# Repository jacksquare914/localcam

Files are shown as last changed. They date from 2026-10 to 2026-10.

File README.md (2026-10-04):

# LocalCam-1 — a local-only WiFi camera

A small 4-layer board that turns a **Luckfox Core1106** system-on-module (Rockchip
RV1106G3) into a network camera that never talks to anyone's cloud. A MIPI CSI-2 sensor
comes in over an FPC, the module encodes H.264/H.265 on-chip, and the stream is served
over RTSP to a local [Frigate](https://frigate.video/) NVR. Object detection runs on the
module's own 1 TOPS NPU, on the camera, not on a server and not on someone else's GPU.

**75 × 44 mm, 4 layers, 1.6 mm, built by JLCPCB.** USB-C in, microSD for storage, a
debug UART header and a recovery button.

> **Status: not ready to order.** 226 of 228 netted pads are connected. Two signals still
> need a trace and both need a part nudged rather than more routing effort — see
> [What is still open](#what-is-still-open). Everything else has been verified; the
> evidence is in [`logs/`](logs/).

---

## Why this board exists

Every consumer camera in this class wants an account, an app, and an outbound
connection. The goal here is the opposite: a camera that is useful precisely because it
is isolated. Four requirements drove the whole design.

1. **Nothing leaves the LAN.** No cloud service, no phone-home, no vendor account. RTSP
   to a local NVR and that is all.
2. **Detection happens on the camera.** The RV1106G3's NPU runs the model, so there is
   no video streaming off-box just so a server can look at it.
3. **It must be repairable and legible.** A board you cannot read is a board you cannot
   fix. That drove the routing style (below) as much as any electrical requirement.
4. **One cable.** USB-C supplies it; everything else is optional.

## What is on it

| | |
|---|---|
| **U1** | Luckfox Core1106 — RV1106G3, Cortex-A7 + RISC-V MCU + NPU + ISP, 256 MB DDR3L, onboard WiFi and 8 GB eMMC options |
| **J3** | 24-pin 0.5 mm FPC to the camera sensor — 2 MIPI data lanes + clock, I²C, MCLK, reset, power-down |
| **J1** | USB-C 2.0 receptacle — power in and USB device, with CC pull-downs and an ESD part (U2) |
| **J2** | microSD (Hirose DM3AT), 4-bit SDMMC, with card-detect |
| **H1** | 5-pin debug header — UART2 plus the recovery line |
| **S1** | reset, **D2** status LED, **F1** 1.5 A polyfuse, **D1** TVS on the 5 V rail |

Full pad-by-pad detail, cross-checked against the vendor pinout, is in
[`docs/pin-assignment-crosscheck.md`](docs/pin-assignment-crosscheck.md).

---

## The design decisions worth arguing about

[`docs/INTENT.md`](docs/INTENT.md) is the long version. The short version:

**The stack-up decides everything.** JLCPCB **JLC04161H-7628**: the 0.2104 mm of 7628
prepreg between F.Cu and the ground plane is the only reason the camera pairs can be
100 Ω. *If you let the fab substitute a stack-up, the pairs silently stop being 100 Ω.*
The order settings are printed by `hardware/make-fab.sh` for exactly that reason.

**In1.Cu is a plane, not a routing layer.** A MIPI pair's return current flows in the
copper directly beneath it; a slot cut in that plane is the classic reason a camera link
passes on the bench and drops frames when the enclosure warms up. The router physically
cannot place a non-GND track there.

**The camera pairs are routed as one trace, then split.** A single centreline is routed
at the full pair width and both traces are generated as parallel offsets of it, so the
gap is constant by construction and the lengths are identical:

| pair | leg / leg | intra-pair skew |
|---|---|---|
| CSI_D1 | 14.51 / 14.51 mm | **0 µm** |
| CSI_CLK | 14.72 / 14.72 mm | **0 µm** |
| CSI_D0 | 14.92 / 14.92 mm | **0 µm** |

Budget was 100 µm. Inter-pair spread is 410 µm against a 1000 µm budget. No pair changes
layer and no pair has a via.

**Orthogonal everywhere, with one deliberate exception.** Every trace runs parallel or
perpendicular to a board edge — 480-odd segments of it — except **18 chamfers, all six
of which belong to camera-pair traces**. Routed fully orthogonal the clock pair could not
stay coupled in the shared FPC channel and came out at 3.0 mm skew, which is a dead MIPI
link. Eighteen chamfers in one corridor buy back 0 µm on all three pairs. Everywhere
else there is room, so nothing cuts a corner.

**The USB-C data pads cross with no vias at all.** A 12-pin receptacle interleaves its
two D− pads with its two D+ pads at 0.5 mm pitch, so the two shorting links must cross
exactly once. A via pair does not fit — a 0.6 mm via needs 0.5 mm of clear radius and the
neighbouring pad edge is 0.35 mm away. So one net crosses *above* the pad row, inside the
connector body, and the other crosses *below* it. They never meet.

**Power rails live on In2.Cu, one via per group.** 0.5 mm of 1 oz outer copper carries
1.44 A at a 10 °C rise (IPC-2221) and the module draws about 0.6 A. +5V and VBUS_IN vias
are doubled, because a single plated barrel carrying a whole rail is the classic
warm-attic failure.

---

## Defects found and fixed along the way

These were real, and most were caught by review rather than by the person who made them.

| # | Defect | Why it mattered |
|---|---|---|
| A-7 | Pad 76 (`VCC3V3_RTC`) had been tied to +3V3 | It sits behind a Schottky inside the module; tying it shorts across that diode. Now deliberately unconnected. |
| A-8 | Camera I²C pull-ups went to +3V3 | Pads 16/17 are in the module's **1.8 V** IO domain — the vendor pinout confirms it. Pulling them to 3.3 V over-drives 1.8 V pins. Now on `+1V8`. |
| A-9 | `VBUS_DET` divider was fed from +3V3 | 100k/100k from 3.3 V gives 1.65 V into pad 24 (`USB_VBUSDET`, a **3.3 V** input) — *below* V_IH, so the pin sat in the indeterminate band. Now from +5V: 2.5 V, a valid high. |
| A-10/11 | No decoupling on +1V8; +5V bulk 71 mm from the module | ~60 mV of droop at 0.6 A with nothing local to absorb a WiFi transmit burst. Added C7 (100 nF on +1V8) and C8 (10 µF local +5V bulk). |
| A-12 | Ground pour ran flush to the board edge | Ignored the 2 mm corner fillets. Now inset 0.25 mm, following the radius. |
| A-13 | Three vias sat **inside pads** | Via-in-pad wicks solder paste during reflow and is not offered at this price tier. |
| A-14 | Two pairs of drills physically overlapped | −0.008 and −0.120 mm hole-to-hole against a 0.20 mm minimum. The fab would have rejected it. |
| A-15 | U2 (the USB ESD part) **was not grounded** | Its ground pad is fenced in by the USB traces, so the pour could not reach it. It now has its own via to the plane. |
| A-16 | The microSD **card-detect pins were not in the netlist at all** | J2 pins 9/10 had no net, so no connectivity check could report them. The stock `Micro_SD_Card` symbol has no such pins; J2 now uses `Micro_SD_Card_Det2`, which matches the DM3AT footprint pin for pin. |

A-15 and A-16 are the instructive ones: both were invisible to a net-level check. A net
with two pads and one trace looks complete whether or not a *third* pad is stranded, and
a pad with no net cannot be reported as disconnected at all. That is what
`tools/padaudit.py` exists to catch.

---

## Repo layout

```
hardware/     the KiCad 10 project — open LocalCam1.kicad_pro
  lib/        the Core1106 symbol and footprint (not in KiCad's stock libraries)
  make-fab.sh one-shot JLCPCB output generator; run it on a machine with KiCad 10
tools/        the sources of truth and the checkers
  spec.py       NETLIST source of truth — 36 parts, 36 nets. Edit this, never the schematic
  placement.py  PLACEMENT source of truth — part positions and the zone list
  gen.py        spec.py  -> LocalCam1.kicad_sch
  genpcb.py     spec.py + placement.py -> LocalCam1.kicad_pcb (placed, netted, unrouted)
  hroute5.py    the router (orthogonal, with coupled differential pairs)
  hroute6.py    the finisher — routes only what is missing, keeping existing copper
  continuity.py per-net island count + true minimum copper-to-copper gap
  padaudit.py   PER-PAD audit with the ground pour simulated  <- the one that finds real bugs
docs/         design intent, the pinout, the cross-check, routing and mechanical notes
vendor/       Luckfox's own Core1106 pinout spreadsheet, module PDF and footprint package
logs/         verification output, kept as evidence rather than summarised
```

## Building and checking it

The schematic and the board are **build outputs**. Do not hand-edit them and expect the
edit to survive.

```bash
cd tools
export KICAD_SYMBOL_DIR=/usr/share/kicad/symbols     # wherever yours live
python3 gen.py        # -> LocalCam1.kicad_sch
python3 genpcb.py     # -> LocalCam1.kicad_pcb  (placed, netted, unrouted)
python3 hroute5.py base.kicad_pcb routed.kicad_pcb   # route it
```

Then check it with something that did not do the routing:

```bash
python3 padaudit.py   ../hardware/LocalCam1.kicad_pcb   # per-pad, pour simulated
python3 continuity.py ../hardware/LocalCam1.kicad_pcb --clearance
```

`padaudit.py` walks every pad that carries a net and answers one question: is this pad in
the same electrical island as the rest of its net? It simulates the ground pour, because
the board ships with pours unfilled so KiCad recomputes them — without that simulation
every GND pad looks disconnected and the answer is useless.

**Fill the zones in KiCad (press `B`) and save before plotting**, or the pours are not in
the Gerbers and the ground plane simply does not exist.

Requires `numpy` and `scipy`.

## Verified, on the delivered board

```
226 / 228 netted pads connected        (pour simulated)
499 segments: 481 orthogonal, 18 chamfers on camera pairs, 0 other angles
108 vias, all 0.6 / 0.3 mm             (0.15 mm annular ring, min is 0.13)
minimum copper-to-copper gap 0.150 mm  (JLCPCB floor is 0.09)
camera pairs: 0 µm intra-pair skew, 410 µm inter-pair spread
45 of 45 used module pads agree with the vendor pinout
```

## What is still open

Two signals, both placement problems rather than routing ones:

| Net | Pad | At | What to do |
|---|---|---|---|
| `SD_D3` | J2.2 | (55.78, 28.51) | Six SD signals funnel through one gap between the module and the socket and D3 does not fit. Give it B.Cu with a via each side, or shift J2 about a millimetre. |
| `VBUS_DET` | R7.2 | (19.41, 32.60) | R7 sits in the channel the USB pair needs between U2 and the module edge. Move it clear — toward y ≈ 35.5 — or rotate it 90°. |

The router was given every chance at these: shape search, two-layer maze, two rip-up
rounds at widening corridors, and a last-resort pass at 0.15 mm / 0.10 mm. Each attempt
either gained nothing or broke three other nets to fix one, and reported that rather than
claiming a win.

**Open question for review:** `R7` currently divides **+5V** (post-fuse). Dividing
**VBUS_IN** (pre-fuse) is what the pin name literally means and still reads high if the
polyfuse opens; +5V instead answers "is my rail actually up?". Both give 2.5 V and both
are valid. One line in `spec.py`.

## Reviewing this board — where to look first

If you have ten minutes: [`docs/INTENT.md`](docs/INTENT.md) §4 for the arguable decisions,
then `logs/VERIFY-pads.log` for what is actually connected. If you have an hour, run
`padaudit.py` yourself and disagree with it.

Things I would most like a second opinion on:

- The two open nets above — is nudging R7 and J2 the right call, or should the floorplan
  change more deeply?
- The USB pair is **not** coupled between U1 and U2, because U2's +5V pin sits physically
  between D− and D+. Over ~8 mm at USB 2.0 that should be fine. Second opinion welcome.
- `+5V` reaches the module through a ~71 mm path. C8 was added locally to cover it, but a
  different floorplan would shorten the path instead.
- Whether grounding both card-detect pins is the right choice versus bringing one out to
  a GPIO with a pull-up.

## Sources

- Luckfox Core1106 pinout, schematic and footprint package —
  <https://wiki.luckfox.com/Core1106/Pinout/> (the files are mirrored in `vendor/`)
- Rockchip RV1106 datasheet V1.7 —
  <https://files.luckfox.com/wiki/Luckfox-Pico/PDF/Rockchip%20RV1106%20Datasheet%20V1.7-20231218.pdf>
- Core1106 product page — <https://www.luckfox.com/Core1106>
- Trace current capacity: IPC-2221. Differential microstrip geometry: IPC-2141.
- JLCPCB capabilities and the JLC04161H-7628 stack-up: JLCPCB's own capability pages.

## Licence

No licence has been chosen yet — which by default means all rights reserved, so pick one
before sharing this widely.

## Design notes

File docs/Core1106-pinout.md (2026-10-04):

# Core1106 pinout — vendor table, with this board's net on every pad

Source: `Core1106-PinOut.xls` from Luckfox's Core1106 footprint package
(<https://wiki.luckfox.com/Core1106/Pinout/>). The vendor columns are reproduced
verbatim; the **Net** column is what LocalCam-1 connects, and blank means the pad is
deliberately left unconnected.

112 castellated pads, 1.0 mm pitch, pad 1 at the arrow, numbered counter-clockwise.

| Pad | Vendor pin name | IO domain | Net on this board | Vendor remark |
|----:|---|:--:|---|---|
| 1 | `VI_CIF_D2_M0/MIPI_CSI_RX_CK1N/LVDS_RX_CK1N/GPI3_B2_d` | 1.8V | — |  |
| 2 | `VI_CIF_D3_M0/MIPI_CSI_RX_CK1P/LVDS_RX_CK1P/GPI3_B3_d` | 1.8V | — |  |
| 3 | `VI_CIF_D0_M0/MIPI_CSI_RX_D3N/LVDS_RX_D3N/GPI3_B0_d` | 1.8V | — |  |
| 4 | `VI_CIF_D1_M0/MIPI_CSI_RX_D3P/LVDS_RX_D3P/GPI3_B1_d` | 1.8V | — |  |
| 5 | `VI_CIF_D4_M0/MIPI_CSI_RX_D2N/LVDS_RX_D2N/GPI3_B4_d` | 1.8V | — |  |
| 6 | `VI_CIF_D5_M0/MIPI_CSI_RX_D2P/LVDS_RX_D2P/GPI3_B5_d` | 1.8V | — |  |
| 7 | `VI_CIF_D6_M0/MIPI_CSI_RX_D1N/LVDS_RX_D1N/GPI3_B6_d` | 1.8V | **CSI_D1_N** |  |
| 8 | `VI_CIF_D7_M0/MIPI_CSI_RX_D1P/LVDS_RX_D1P/GPI3_B7_d` | 1.8V | **CSI_D1_P** |  |
| 9 | `VI_CIF_D8_M0/MIPI_CSI_RX_CK0N/LVDS_RX_CK0N/GPI3_C0_d` | 1.8V | **CSI_CLK_N** |  |
| 10 | `VI_CIF_D9_M0/MIPI_CSI_RX_CK0P/LVDS_RX_CK0P/GPI3_C1_d` | 1.8V | **CSI_CLK_P** |  |
| 11 | `VI_CIF_CLKI_M0/MIPI_CSI_RX_D0N/LVDS_RX_D0N/GPI3_C2_d` | 1.8V | **CSI_D0_N** |  |
| 12 | `VI_CIF_HREF_M0/MIPI_CSI_RX_D0P/LVDS_RX_D0P/GPI3_C3_d` | 1.8V | **CSI_D0_P** |  |
| 13 | `VI_CIF_D15/PWM1_M2/GPIO3_D3_d` | 1.8V | **CAM_PWDN** |  |
| 14 | `VI_CIF_D14/UART5_CTS_M2/I2C3_SDA_M2/GPIO3_D2_d` | 1.8V | — |  |
| 15 | `VI_CIF_D13/UART5_RTS_M2/I2C3_SCL_M2/GPIO3_D1_d` | 1.8V | — |  |
| 16 | `VI_CIF_D11/UART5_TX_M2/I2C4_SCL_M2/GPIO3_C7_d` | 1.8V | **CAM_SCL** |  |
| 17 | `VI_CIF_D12/UART5_RX_M2/I2C4_SDA_M2/GPIO3_D0_d` | 1.8V | **CAM_SDA** |  |
| 18 | `VI_CIF_VSYNC_M0/GPIO3_C5_d` | 1.8V | **CAM_RST** |  |
| 19 | `VI_CIF_CLKO_M0/MIPI_CLK0_OUT/GPIO3_C4_d` | 1.8V | **MCLK0** |  |
| 20 | `VI_CIF_D10/PWM7_IR_M2/MIPI_CLK1_OUT/GPIO3_C6_d` | 1.8V | — |  |
| 21 | `GND` | - | **GND** |  |
| 22 | `USB_N` | - | **USB_DM** |  |
| 23 | `USB_P` | - | **USB_DP** |  |
| 24 | `USB_VBUSDET` | 3.3V | **VBUS_DET** |  |
| 25 | `GND` | - | **GND** |  |
| 26 | `SARADC_IN0/GPIO4_C0_z` | 1.8V | **ADC0_RECOV** |  |
| 27 | `SARADC_IN1/PWM1_M1/GPIO4_C1_z` | 1.8V | — |  |
| 28 | `GND` | - | **GND** |  |
| 29 | `GND` | - | **GND** |  |
| 30 | `CODEC_LINEOUT` | 1.8V | — |  |
| 31 | `CODEC_MICBIAS` | 1.8V | — |  |
| 32 | `CODEC_MIC0N` | 1.8V | — |  |
| 33 | `CODEC_MIC0P` | 1.8V | — |  |
| 34 | `CODEC_MIC1N` | 1.8V | — |  |
| 35 | `CODEC_MIC1P` | 1.8V | — |  |
| 36 | `GND` | - | **GND** |  |
| 37 | `EMMC_D0/FSPI_D0/GPIO4_A4_u` | 3.3V | — | When EMMC is installed, it will be disconnected. |
| 38 | `EMMC_D1/FSPI_D1/GPIO4_A3_u` | 3.3V | — |  |
| 39 | `EMMC_D2/FSPI_D2/GPIO4_A2_u` | 3.3V | — |  |
| 40 | `EMMC_D3/FSPI_D3/GPIO4_A6_u` | 3.3V | — |  |
| 41 | `EMMC_D4/SPI1_CS0_M0/UART1_TX_M2/I2C2_SDA_M1/GPIO4_A5_u` | 3.3V | — |  |
| 42 | `EMMC_D5/SPI1_CLK_M0/UART1_RX_M2/I2C2_SCL_M1/GPIO4_A7_u` | 3.3V | — |  |
| 43 | `EMMC_D6/SPI1_MOSI_M0/UART0_TX_M2/I2C0_SCL_M1/GPIO4_A1_u` | 3.3V | — |  |
| 44 | `EMMC_D7/SPI1_MISO_M0/UART0_RX_M2/I2C0_SDA_M1/GPIO4_A0_u` | 3.3V | — |  |
| 45 | `EMMC_CMD/FSPI_CS0/GPIO4_B0_u` | 3.3V | — |  |
| 46 | `EMMC_CLK/FSPI_CLK/GPIO4_B1_d` | 3.3V | — |  |
| 47 | `GND` | - | **GND** |  |
| 48 | `SDMMC_DET/GPIO3_A1_u` | 3.3V | — | When Wifi Module is installed, it will be disconnected. |
| 49 | `SDMMC_D0/UART2_RX_M0/PWM8_M0/GPIO3_A3_u` | 3.3V | **SD_D0** |  |
| 50 | `SDMMC_D1/UART2_TX_M0/PWM9_M0/GPIO3_A2_u` | 3.3V | **SD_D1** |  |
| 51 | `SDMMC_D2/UART5_RX_M0/JTAG_CPU_TCK_M0/JTAG_HPMCU_TCK_M1/GPIO3_A7_u` | 3.3V | **SD_D2** |  |
| 52 | `SDMMC_D3/UART5_TX_M0/JTAG_CPU_TMS_M0/JTAG_HPMCU_TMS_M1/GPIO3_A6_u` | 3.3V | **SD_D3** |  |
| 53 | `SDMMC_CMD/UART5_CTS_M0/I2C0_SDA_M2/JTAG_LPMCU_TMS_M1/PWM11_IR_M0/GPIO3_A5_u` | 3.3V | **SD_CMD** |  |
| 54 | `SDMMC_CLK/UART5_RTS_M0/I2C0_SCL_M2/JTAG_LPMCU_TCK_M1/PWM10_M0/GPIO3_A4_d` | 3.3V | **SD_CLK** |  |
| 55 | `GND` | - | **GND** |  |
| 56 | `GND` | - | **GND** |  |
| 57 | `GND` | - | **GND** |  |
| 58 | `UART0_RX_M0/CLK_32K/CLK_REFOUT/RTC_CLKO/GPIO0_A0_z` | 3.3V | **LED_STAT** |  |
| 59 | `UART0_TX_M0/PWM2_M0/GPIO0_A1_d` | 3.3V | — |  |
| 60 | `PWM3_IR_M0/GPIO0_A2_d` | 3.3V | — |  |
| 61 | `PWR_CTRL_M1/GPIO0_A3_u` | 3.3V | — |  |
| 62 | `PWR_CTRL_M0/PWM1_M0/GPIO0_A4_d` | 3.3V | — |  |
| 63 | `I2C1_SCL_M0/UART1_RTS_M0/PWM5_M0/GPIO0_A5_d` | 3.3V | — | When Wifi Module is installed, it will be disconnected. |
| 64 | `I2C1_SDA_M0/UART1_CTS_M0/PWM6_M0/GPIO0_A6_d` | 3.3V | — |  |
| 65 | `UART3_TX_M0/I2C2_SCL_M0/PWM7_IR_M0/GPIO1_A0_d` | 3.3V | — |  |
| 66 | `UART3_RX_M0/I2C2_SDA_M0/PMU_DEBUG/PWM4_M0/GPIO1_A1_d` | 3.3V | — |  |
| 67 | `PWM0_M0/CPU_AVS/VI_CIF_D0_M1/GPIO1_A2_d` | 3.3V | — |  |
| 68 | `UART1_TX_M0/I2C0_SCL_M0/GPIO1_A3_d` | 3.3V | — | When Wifi Module is installed, it will be disconnected. |
| 69 | `UART1_RX_M0/I2C0_SDA_M0/GPIO1_A4_d` | 3.3V | — |  |
| 70 | `UART4_RX_M0/PWM3_IR_M1/GPIO1_B0_d` | 3.3V | — |  |
| 71 | `UART4_TX_M0/PWM7_IR_M1/SPI1_CS1_M0/VI_CIF_D1_M1/GPIO1_B1_d` | 3.3V | — |  |
| 72 | `JTAG_CPU_TCK_M1/UART2_TX_M1/JTAG_HPMCU_TCK_M0/JTAG_LPMCU_TCK_M0/GPIO1_B2_d` | 3.3V | **UART2_TX** |  |
| 73 | `JTAG_CPU_TMS_M1/UART2_RX_M1/JTAG_HPMCU_TMS_M0/JTAG_LPMCU_TMS_M0/GPIO1_B3_u` | 3.3V | **UART2_RX** |  |
| 74 | `NPOR` | - | **NPOR_RST** |  |
| 75 | `GND` | - | **GND** |  |
| 76 | `VCC3V3_RTC` | - | — |  |
| 77 | `VCC_1V8` | - | **+1V8** |  |
| 78 | `VCC_3V3` | - | **+3V3** |  |
| 79 | `VCC5V0_SYS` | - | **+5V** |  |
| 80 | `VCC5V0_SYS` | - | **+5V** |  |
| 81 | `VCC5V0_SYS` | - | **+5V** |  |
| 82 | `GND` | - | **GND** |  |
| 83 | `GND` | - | **GND** |  |
| 84 | `GND` | - | **GND** |  |
| 85 | `FEPHY_RXN` | - | — |  |
| 86 | `FEPHY_RXP` | - | — |  |
| 87 | `FEPHY_TXN` | - | — |  |
| 88 | `FEPHY_TXP` | - | — |  |
| 89 | `GND` | - | **GND** |  |
| 90 | `VO_LCDC_CLK/VI_CIF_CLKO_M1/I2C3_SCL_M1/UART5_TX_M1/PWM11_IR_M2/AUD_DSM_N/GPIO1_D3_d` | 3.3V | — |  |
| 91 | `VO_LCDC_VSYNC/VI_CIF_VSYNC_M1/I2C3_SDA_M1/UART5_RX_M1/SPI0_CS1_M0/PWM0_M1/AUD_DSM_P/GPIO1_D2_d` | 3.3V | — |  |
| 92 | `VO_LCDC_HSYNC/VI_CIF_HREF_M1/PWM10_M2/UART5_CTS_M1/UART3_RX_M1/GPIO1_D1_d` | 3.3V | — |  |
| 93 | `VO_LCDC_DEN/VI_CIF_CLKI_M1/PWM3_IR_M2/UART5_RTS_M1/UART3_TX_M1/GPIO1_D0_d` | 3.3V | — |  |
| 94 | `VO_LCDC_D0/VI_CIF_D9_M1/PWM11_IR_M1/UART4_CTS_M1/GPIO1_C7_d` | 3.3V | — |  |
| 95 | `VO_LCDC_D1/VI_CIF_D8_M1/PWM10_M1/UART4_RTS_M1/GPIO1_C6_d` | 3.3V | — |  |
| 96 | `VO_LCDC_D2/VI_CIF_D7_M1/PWM9_M1/UART4_TX_M1/SDIO_D2_M1/GPIO1_C5_d` | 3.3V | — |  |
| 97 | `VO_LCDC_D3/VI_CIF_D6_M1/PWM8_M1/UART4_RX_M1/SDIO_D3_M1/GPIO1_C4_d` | 3.3V | — |  |
| 98 | `VO_LCDC_D4/VI_CIF_D5_M1/PWM6_M2/I2C4_SDA_M1/SDIO_CMD_M1/SPI0_MISO_M0/GPIO1_C3_d` | 3.3V | — |  |
| 99 | `VO_LCDC_D5/VI_CIF_D4_M1/PWM5_M2/I2C4_SCL_M1/SDIO_CLK_M1/SPI0_MOSI_M0/GPIO1_C2_d` | 3.3V | — |  |
| 100 | `VO_LCDC_D6/VI_CIF_D3_M1/PWM4_M2/SPI0_CLK_M0/SDIO_D0_M1/GPIO1_C1_d` | 3.3V | — |  |
| 101 | `VO_LCDC_D7/VI_CIF_D2_M1/PWM2_M2/SPI0_CS0_M0/SDIO_D1_M1/GPIO1_C0_d` | 3.3V | — |  |
| 102 | `SDIO_D1_M0/I2S0_SCLK/VO_LCDC_D8/UART1_CTS_M1/I2C4_SDA_M0/GPIO2_A0_d` | 3.3V | — |  |
| 103 | `SDIO_D0_M0/I2S0_LRCK/VO_LCDC_D9/UART1_RTS_M1/I2C4_SCL_M0/GPIO2_A1_d` | 3.3V | — |  |
| 104 | `SDIO_CLK_M0/I2S0_MCLK/VO_LCDC_D10/GPIO2_A2_d` | 3.3V | — |  |
| 105 | `SDIO_CMD_M0/I2S0_SDO3_SDI1/VO_LCDC_D11/GPIO2_A3_d` | 3.3V | — |  |
| 106 | `SDIO_D3_M0/I2S0_SDO0/VO_LCDC_D12/UART1_TX_M1/GPIO2_A4_d` | 3.3V | — |  |
| 107 | `SDIO_D2_M0/I2S0_SDI0/VO_LCDC_D13/UART1_RX_M1/GPIO2_A5_d` | 3.3V | — |  |
| 108 | `UART0_RTS_M1/I2S0_SDO2_SDI2/VO_LCDC_D14/PWM2_M1/I2C3_SCL_M0/FLASH_TRIG_OUT/GPIO2_A6_d` | 3.3V | — |  |
| 109 | `UART0_CTS_M1/I2S0_SDO1_SDI3/VO_LCDC_D15/PWM4_M1/I2C3_SDA_M0/PRELIGHT_TRIG_OUT/GPIO2_A7_d` | 3.3V | — |  |
| 110 | `UART0_RX_M1/I2C1_SCL_M1/VO_LCDC_D16/PWM5_M1/GPIO2_B0_d` | 3.3V | — |  |
| 111 | `UART0_TX_M1/I2C1_SDA_M1/VO_LCDC_D17/PWM6_M1/GPIO2_B1_d` | 3.3V | — |  |
| 112 | `GND` | - | **GND** |  |

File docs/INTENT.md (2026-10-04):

# LocalCam-1 Rev A2 — design intent

Why this board is laid out the way it is. Written so that in six months you can open
the file, disagree with something, and know what you are trading away.

---

## 1. What the board is

A local-only WiFi camera. A Luckfox Core1106 module (Rockchip RV1106G3) takes a MIPI
CSI-2 sensor over an FPC, encodes H.264/H.265 on-chip, serves RTSP to Frigate, and runs
cat detection on its own 1 TOPS NPU. Nothing leaves the LAN. The board is 75 × 44 mm,
four layers, 1.6 mm, built by JLCPCB.

Everything on this board exists to do one of four things: get 5 V in, get the camera
in, get video out over WiFi, and let you recover the thing when it will not boot.

---

## 2. The stack-up, and why it decides everything else

    F.Cu      35 µm    signal — short horizontal runs, all the fine-pitch escapes
    prepreg  210.4 µm  7628, Er 4.4     <-- this number sets the impedance
    In1.Cu    15.2 µm  SOLID GROUND. Nothing else is allowed on it.
    core    1065   µm  Er 4.6
    In2.Cu    15.2 µm  power rails
    prepreg  210.4 µm
    B.Cu      35 µm    signal — vertical runs and everything crossing under the module

JLCPCB's **JLC04161H-7628**. The 0.2104 mm of 7628 between F.Cu and the ground plane is
the entire reason the camera pairs can be 100 Ω: a microstrip 0.22 mm wide over that
dielectric is 100 Ω differential at a 0.18 mm gap (IPC-2141). **If you let JLCPCB pick a
different stack-up at order time, the pairs stop being 100 Ω** and nothing on the board
tells you. That is why the order settings are spelled out in `make-fab.sh`.

In1.Cu is a plane and not a routing layer. That is not tidiness — it is the return path.
A MIPI pair's return current flows in the copper directly beneath it, and a slot cut in
that plane forces the return to detour around it. That is the classic failure where a
camera link works on the bench and drops frames when the enclosure warms up. The router
physically cannot put a non-GND track on In1.Cu; the layer is pre-loaded as GND in its
occupancy model, so anything else is a collision.

In2.Cu carries the rails. It is not a second ground.

---

## 3. Routing philosophy

The brief was: do not make it look like a machine did it. Concretely that meant:

**Orthogonal, with exactly one exception.** Every trace on this board runs parallel or
perpendicular to a board edge. 461 of 479 segments are orthogonal; the other 18 are
45° chamfers and **all 18 belong to the six camera-pair traces** — three per trace, in
one corridor. Nothing else on the board turns at an angle, and the build fails if it
does: the geometry gate allows a 45° only on a CSI net, and a repair pass rebuilds
anything else as an L or removes it and reports it.

Why the camera pairs are the exception, and nothing else is: a square corner needs the
full trace width plus clearance to turn, twice, where a chamfer turns inside the trace's
own width. Three pairs share one channel from the FPC to the module, and routed fully
orthogonal the clock pair could not stay coupled — it came out at **3.0 mm intra-pair
skew against a 100 µm budget**, which is a dead MIPI link. Eighteen chamfers in one
corridor buys back 0 µm on all three pairs. Everywhere else on this board there is room,
so there is no reason to cut a corner and it does not.

**Layers have a direction.** F.Cu trends horizontal, B.Cu trends vertical. The router
pays a cost penalty for going against the grain, and its maze search moves on four
neighbours, not eight, so an oblique run is not merely discouraged — it is unreachable. This is the oldest convention in the
trade and it is why you can follow a net by eye: if it turns, it changed layer, and
there is a via there.

**Escapes are perpendicular.** A trace leaves a pad along the pad's own long axis,
straight, before it turns. On the module's castellated 1.0 mm pitch and the FPC's
0.5 mm pitch there is no other legal way out, and it is also simply what a person draws.

**Shapes before search.** The router tries clean L and Z shapes first and only falls
back to a maze search when geometry cannot do it. A maze path is recognisably
machine-made; an L is not.

**Necked escapes.** A 0.5 mm power rail cannot physically leave a 1.0 mm-pitch
castellated pad at 0.2 mm clearance — the arithmetic does not close. So rails leave at
0.3 mm and fatten once clear of the pad field, and USB stubs leave 0.5 mm-pitch
connector pads at 0.2 mm. This is standard fanout practice, not a compromise.

---

## 4. The decisions worth arguing about

### 4.1 The camera pairs are routed as one trace, then split

The three CSI pairs are not two traces that happen to run near each other. A single
centreline is routed at the full pair width (2 × 0.22 + 0.18 = 0.62 mm), and the two
traces are generated as parallel offsets of it. The consequence is that the gap is
constant by construction, the corners are mirrored, and the lengths are identical.

    CSI_D1   14.51 / 14.51 mm     skew 0 µm
    CSI_CLK  14.72 / 14.72 mm     skew 0 µm
    CSI_D0   14.92 / 14.92 mm     skew 0 µm

Measured off the finished file by a script that did not do the routing, not claimed by
the router.

Budget was 100 µm intra-pair and 1000 µm between pairs. Actual: **0 µm** and 410 µm.
No pair changes layer, no pair has a via, and all three stay on F.Cu over unbroken
In1.Cu the whole way. They are routed in the physical order they appear on the FPC so
the bus nests instead of crossing.

The order the three are routed in matters: whichever goes first shapes the channel for
the other two. The build tries several orderings and keeps the one that couples all
three. That is worth knowing if you move a part and one pair suddenly routes loose.

### 4.2 The USB-C data pads cross without a single via

A 12-pin USB-C receptacle interleaves its two D− pads with its two D+ pads
(B7 D−, A6 D+, A7 D−, B6 D+, at 0.5 mm pitch). To short A6–B6 and A7–B7 for reversible
orientation the two links **must** cross exactly once.

The obvious answer — a via pair — does not fit. A 0.6 mm via needs 0.5 mm of clear
radius and the neighbouring pad edge is 0.35 mm away. It is not a question of trying
harder; the geometry is closed.

So the crossing is a **bowtie**: one net crosses *above* the pad row, inside the
connector body where the board is empty, and the other crosses *below* it. They never
meet, so nothing has to change layer. No vias, no stubs, no compromise.

### 4.3 The USB pair is not coupled, and that is deliberate

U2 (the USBLC6 ESD part) has its **+5V pin physically between D− and D+**. There is no
way to route a coupled pair into that pinout. The U1↔U2 run is therefore two
single-ended traces at the correct 0.27 mm width.

Over ~8 mm at USB 2.0 full/high speed this is not a problem in practice, but it is a
known deviation rather than an oversight. If you want it coupled, U2 has to move or be
replaced with a part whose D± pins are adjacent.

The J1↔U2 stubs are routed at the default 0.2 mm rather than 0.27 mm. Holding them to
the USB class made them unroutable through U2's pad field, and 5 mm of 0.2 mm trace is
roughly 95 Ω instead of 90 Ω — an irrelevant discontinuity at USB 2.0. The
impedance-controlled run is U1↔U2 and it keeps the class.

### 4.4 Power: one via per group, and the rails live on In2.Cu

Rail pads that sit near each other are joined on the top layer as a local group, and
each group drops **one** via into the power layer. The alternative — a via at every rail
pad — is electrically slightly better and visually much worse, and on this board it
crowded the pull-up resistors and decoupling caps around the camera bus badly enough
that their own signals could not escape.

The rails are traces on In2.Cu, not pours. 0.5 mm of 1 oz outer copper carries 1.44 A at
a 10 °C rise (IPC-2221); the module draws about 0.6 A. That is 2.4× margin, and a routed
power layer is easier to read and to change than a set of overlapping pours.

**+5V and VBUS_IN vias are doubled.** A single plated barrel carrying an entire rail is
the classic warm-attic failure — barrel fatigue accelerates with thermal cycling, and
when it goes the module loses its supply. Companion vias cost nothing and halve the
current per barrel.

### 4.5 Ground is a plane plus stitching, not a net to be routed

GND pads connect through the F.Cu and B.Cu pours. The stitching vias are not there to
make the connection — they are there to give each pad a short path to the In1.Cu plane,
which is what actually matters for return current. They are placed last, into whatever
space is left, which is the correct order: they are the most flexible thing on the board.

Some pads have no room for a stitching via. They are still connected through the pour;
they just have a longer return path. The build lists them by name rather than quietly
skipping them.

### 4.6 Pad-to-pad clearance is the footprint's problem, not the trace's

A 0.5 mm-pitch FPC pin offers exactly 0.35 mm of lateral room, and a 0.2 mm trace at
0.15 mm clearance needs exactly 0.35 mm. Enforced naively, *nothing can ever leave an
FPC pad*. The clearance rule is therefore not applied inside a pad's own footprint area
— the fab guarantees the pad gaps, and this is how every real router behaves. Outside
the pad, full clearance applies.

---

## 5. What changed in Rev A2, and why

These came out of an independent review and are real defects, not polish.

| # | Change | Why |
|---|---|---|
| A-9 | **R7 moved from +3V3 to +5V** | The "VBUS detect" divider was fed from +3V3, giving a fixed 1.65 V into U1 pad 24 — **below** a 3.3 V input's V_IH, so the pin sat in the indeterminate band. From +5V the divider gives 2.5 V, a valid logic high, and it now does what the netlist comment always claimed. |
| A-10 | **C7 added — 100 nF on +1V8** | There was no decoupling on the 1.8 V rail at all. It feeds the camera's IO reference and the I²C pull-ups. |
| A-11 | **C8 added — 10 µF local +5V bulk** | C1 (47 µF) sits at the fuse, 71 mm and roughly 100 mΩ from the module's power pins — about 60 mV of droop at 0.6 A, with nothing local to absorb a WiFi transmit step. C8 sits beside pads 79–81. |
| A-12 | **Ground pour inset 0.25 mm, following the corner radius** | The pour was the raw 75 × 44 rectangle. It ignored the 2 mm corner fillets and ran flush to the cut line. JLCPCB wants 0.2 mm copper-to-edge. |
| A-13 | **No via may overlap any pad** | Three vias had landed inside pads. Via-in-pad wicks solder paste during reflow and is not offered at this price tier. |
| A-14 | **Via hole-to-hole enforced at 0.55 mm centres** | Two pairs of drills physically overlapped (−0.008 and −0.120 mm). JLCPCB's minimum is 0.20 mm hole-to-hole. |
| A-15 | **+5V and VBUS_IN vias doubled** | See 4.4. |

C7 and C8 change the BOM by two parts. Everything else is layout-only.

---

## 6. Things that are true and that you should not "fix"

- **Pad 76 (VCC3V3_RTC) is deliberately unconnected.** Inside the module it sits behind
  Schottky D1. Tying it to +3V3 shorts across that diode. The Drive design brief has
  this wrong; this file is correct.
- **The I²C pull-ups go to +1V8, not +3V3.** The camera bank (pads 7–20) is a 1.8 V IO
  domain. Pulling those lines to 3.3 V over-drives the pins.
- **Pads 77 and 78 are outputs.** VCC_1V8 and VCC_3V3 come *out* of the module's PMIC.
  Only 5 V goes in, on pads 79/80/81.
- **The camera pairs have no test points and no stubs.** That is not an omission.

---

## 7. How to change this board without breaking it

`spec.py` is the netlist source of truth and `placement.py` is the placement source of
truth. The schematic and the board are **build outputs** — never hand-edit them and
expect the edit to survive.

    python3 gen.py        # -> LocalCam1.kicad_sch
    python3 genpcb.py     # -> LocalCam1.kicad_pcb  (placed, netted, unrouted)
    python3 hroute5.py base2.kicad_pcb routed.kicad_pcb    # route it

Verify with something that did not do the routing:

    python3 continuity.py routed.kicad_pcb --clearance

That rasterises every piece of copper — pads, tracks, vias, filled pours — joins layers
through vias, and counts how many electrically separate islands each net forms.
**One island means the net is whole.** It also reports the true minimum copper-to-copper
distance using a Euclidean distance transform, so the number it prints is the real gap,
not a grid artefact.

Fill the zones in KiCad (press `B`) and save before running it, or the pours are ignored
and ground will look disconnected.

---

## 8. What is still open, and exactly how to close it

Two pads out of 226 are not connected. Verified per-pad by `padaudit.py`, which simulates
the ground pour, so this is not an unfilled-zone artefact:

    SD_D3     J2.2   at (55.77, 28.50)
    VBUS_DET  R7.2   at (19.41, 32.60)

Both were attacked by the router from every direction it has — shape search, two-layer
maze, two rounds of rip-up at widening corridors, and a last-resort pass at
0.15 mm / 0.10 mm. Each time it reported no gain rather than breaking something else to
claim a win. They are placement problems, not routing problems:

- **VBUS_DET R7.2 → U1.24 (21, 30.5).** R7 sits at (18.9, 32.6), directly in the channel
  the USB pair needs between U2 and the module's left edge. Move R7 clear of that
  channel — down toward y ≈ 35.5, or rotate it 90° — and the tap has a straight run.
- **SD_D3 J2.2 → U1.52.** Six SD signals leave the module's bottom edge into one gap
  between the module and the microSD socket, and D3 is the one that does not fit. Either
  give it B.Cu (a via each side, running under the bus) or shift J2 a millimetre.

Either is a two-minute job by hand in KiCad, or change `placement.py` and re-run
`hroute5.py` followed by `hroute6.py`.

**A note on how these were found.** The earlier `continuity.py` island count said a net
was broken but not which pad. `padaudit.py` answers per pad, and with the pour simulated
it caught something the island count had let me wave away: U2's ground pad was fenced in
by the USB traces, so the pour could not reach it and **U2 was not grounded at all**.
That is fixed — it now has its own via to the In1.Cu plane. Run `padaudit.py` after any
change; it is the check that actually tells you the truth about a single pin.

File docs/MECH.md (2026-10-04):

# LocalCam-1 mechanical facts (Phase 2 inputs)

## Core1106 module (U1)
| Item | Value | Source |
|---|---|---|
| Outline | 30.00 x 30.00 mm | Waveshare dimension drawing `Core11061408-details-size.jpg` |
| PCB thickness | 1.60 +/- 0.1 mm | same |
| Component side | **top only**; underside is flat | same (side view) |
| Max component height | 4.20 mm above PCB (5.50 mm total) | same |
| Castellations | 112, 1.00 mm pitch, 28 per side, pad 0.7 x 1.5 mm at +/-15.0 mm | `Core1106-SMT.kicad_mod` |
| Pin 1 | top-left corner (triangle marker), numbering runs down the left edge | drawing + PinOut.xls |
| Antenna | **IPEX 1.0 (u.FL) connector on the module, bottom-right corner**, external antenna required | Waveshare page + module schematic ANT1 (GND/DATA/GND) + drawing |
| Carrier copper under module | allowed, except Luckfox's keep-out ring (F&B.Cu: no tracks/vias/pads/pour) at x[-12.15,11.40] y[-11.65,9.02] rel. module centre, 0.25 mm wide | `Core1106-SMT.kicad_mod` zones |
| Carrier cut-out under module | **not required** (flat underside) | drawing |

## Consequences for the carrier
- No copper antenna keep-out on the carrier (antenna is external via IPEX). Reserve headroom above the module's bottom-right corner for the u.FL pigtail and pick an antenna mount point on the case.
- Case must clear 5.5 mm above the carrier's top surface over the module footprint, plus pigtail bend radius (~5 mm) at the IPEX corner.
- All carrier components on the top side (JLCPCB single-side assembly); nothing under the module on the bottom is needed.
- Module is hand-soldered (castellated, not on JLCPCB's placement list); the carrier pads follow Luckfox's footprint exactly.

## Camera I2C pad choice (Phase 2 finding A-8)
Module schematic labels pads 16/17 as `MIPI_I2C_SCL/SDA` (= I2C4_M2 per PinOut.xls). Pads 14/15 are I2C3_M2 - electrically valid but not what Luckfox's stock camera device-tree expects. Spec moved CAM_SCL/CAM_SDA to 16/17 so the SDK's default camera config works unmodified.

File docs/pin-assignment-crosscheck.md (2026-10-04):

# Pin assignment cross-check

Every U1 pad this design uses, checked against the function the vendor pinout gives
that pad. Generated by `tools/crosscheck_pins.py`, not written by hand.

**45 pads used, 45 agree with the vendor table, 0 to check.**

| Pad | Net | Vendor pin name | IO domain | Verdict |
|----:|---|---|:--:|:--:|
| 7 | `CSI_D1_N` | `VI_CIF_D6_M0/MIPI_CSI_RX_D1N/LVDS_RX_D1N/GPI3_B6_d` | 1.8V | OK |
| 8 | `CSI_D1_P` | `VI_CIF_D7_M0/MIPI_CSI_RX_D1P/LVDS_RX_D1P/GPI3_B7_d` | 1.8V | OK |
| 9 | `CSI_CLK_N` | `VI_CIF_D8_M0/MIPI_CSI_RX_CK0N/LVDS_RX_CK0N/GPI3_C0_d` | 1.8V | OK |
| 10 | `CSI_CLK_P` | `VI_CIF_D9_M0/MIPI_CSI_RX_CK0P/LVDS_RX_CK0P/GPI3_C1_d` | 1.8V | OK |
| 11 | `CSI_D0_N` | `VI_CIF_CLKI_M0/MIPI_CSI_RX_D0N/LVDS_RX_D0N/GPI3_C2_d` | 1.8V | OK |
| 12 | `CSI_D0_P` | `VI_CIF_HREF_M0/MIPI_CSI_RX_D0P/LVDS_RX_D0P/GPI3_C3_d` | 1.8V | OK |
| 13 | `CAM_PWDN` | `VI_CIF_D15/PWM1_M2/GPIO3_D3_d` | 1.8V | OK |
| 16 | `CAM_SCL` | `VI_CIF_D11/UART5_TX_M2/I2C4_SCL_M2/GPIO3_C7_d` | 1.8V | OK |
| 17 | `CAM_SDA` | `VI_CIF_D12/UART5_RX_M2/I2C4_SDA_M2/GPIO3_D0_d` | 1.8V | OK |
| 18 | `CAM_RST` | `VI_CIF_VSYNC_M0/GPIO3_C5_d` | 1.8V | OK |
| 19 | `MCLK0` | `VI_CIF_CLKO_M0/MIPI_CLK0_OUT/GPIO3_C4_d` | 1.8V | OK |
| 21 | `GND` | `GND` | - | OK |
| 22 | `USB_DM` | `USB_N` | - | OK |
| 23 | `USB_DP` | `USB_P` | - | OK |
| 24 | `VBUS_DET` | `USB_VBUSDET` | 3.3V | OK |
| 25 | `GND` | `GND` | - | OK |
| 26 | `ADC0_RECOV` | `SARADC_IN0/GPIO4_C0_z` | 1.8V | OK |
| 28 | `GND` | `GND` | - | OK |
| 29 | `GND` | `GND` | - | OK |
| 36 | `GND` | `GND` | - | OK |
| 47 | `GND` | `GND` | - | OK |
| 49 | `SD_D0` | `SDMMC_D0/UART2_RX_M0/PWM8_M0/GPIO3_A3_u` | 3.3V | OK |
| 50 | `SD_D1` | `SDMMC_D1/UART2_TX_M0/PWM9_M0/GPIO3_A2_u` | 3.3V | OK |
| 51 | `SD_D2` | `SDMMC_D2/UART5_RX_M0/JTAG_CPU_TCK_M0/JTAG_HPMCU_TCK_M1/GPIO3_A7_u` | 3.3V | OK |
| 52 | `SD_D3` | `SDMMC_D3/UART5_TX_M0/JTAG_CPU_TMS_M0/JTAG_HPMCU_TMS_M1/GPIO3_A6_u` | 3.3V | OK |
| 53 | `SD_CMD` | `SDMMC_CMD/UART5_CTS_M0/I2C0_SDA_M2/JTAG_LPMCU_TMS_M1/PWM11_IR_M0/GPIO3_A5_u` | 3.3V | OK |
| 54 | `SD_CLK` | `SDMMC_CLK/UART5_RTS_M0/I2C0_SCL_M2/JTAG_LPMCU_TCK_M1/PWM10_M0/GPIO3_A4_d` | 3.3V | OK |
| 55 | `GND` | `GND` | - | OK |
| 56 | `GND` | `GND` | - | OK |
| 57 | `GND` | `GND` | - | OK |
| 58 | `LED_STAT` | `UART0_RX_M0/CLK_32K/CLK_REFOUT/RTC_CLKO/GPIO0_A0_z` | 3.3V | OK |
| 72 | `UART2_TX` | `JTAG_CPU_TCK_M1/UART2_TX_M1/JTAG_HPMCU_TCK_M0/JTAG_LPMCU_TCK_M0/GPIO1_B2_d` | 3.3V | OK |
| 73 | `UART2_RX` | `JTAG_CPU_TMS_M1/UART2_RX_M1/JTAG_HPMCU_TMS_M0/JTAG_LPMCU_TMS_M0/GPIO1_B3_u` | 3.3V | OK |
| 74 | `NPOR_RST` | `NPOR` | - | OK |
| 75 | `GND` | `GND` | - | OK |
| 77 | `+1V8` | `VCC_1V8` | - | OK |
| 78 | `+3V3` | `VCC_3V3` | - | OK |
| 79 | `+5V` | `VCC5V0_SYS` | - | OK |
| 80 | `+5V` | `VCC5V0_SYS` | - | OK |
| 81 | `+5V` | `VCC5V0_SYS` | - | OK |
| 82 | `GND` | `GND` | - | OK |
| 83 | `GND` | `GND` | - | OK |
| 84 | `GND` | `GND` | - | OK |
| 89 | `GND` | `GND` | - | OK |
| 112 | `GND` | `GND` | - | OK |

## What this check establishes

- The three MIPI pairs land on the vendor's own CSI RX D1/CK0/D0 pairs, in that
  order, and every one of those pads is in the **1.8 V** IO domain.
- `CAM_SCL`/`CAM_SDA` are on **I2C4_M2** (pads 16/17), which Luckfox labels as the
  MIPI camera I2C. Both pads are 1.8 V, which is why the pull-ups go to `+1V8` and not
  `+3V3` — pulling them to 3.3 V would over-drive 1.8 V pins.
- `VBUS_DET` is on pad 24, `USB_VBUSDET`, in the **3.3 V** domain. That is the
  reason the divider had to move off `+3V3`: 100k/100k from 3.3 V gives 1.65 V, which is
  below a 3.3 V input's V_IH, so the pin sat in the indeterminate band. From `+5V` it is
  2.5 V, a valid logic high.
- `ADC0_RECOV` is on `SARADC_IN0` (pad 26), a **1.8 V** input — hence the 1 k series
  resistor between it and the exposed header pin.
- Pads 77/78 are `VCC_1V8`/`VCC_3V3` and pads 79/80/81 are `VCC5V0_SYS`. Only 5 V
  goes **in**; 1.8 V and 3.3 V come **out** of the module's own PMIC.
- Pad 76 is `VCC3V3_RTC` and is deliberately left unconnected. See the design intent.
- Pads the vendor marks as taken by fitted options are avoided: pad 37 (eMMC),
  pads 48, 63 and 68 (WiFi module).

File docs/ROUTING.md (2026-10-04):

# LocalCam-1 Rev A — hand-routing sheet

Board is placed, netted and set up. Nothing is routed. Everything below is already
configured in the project — you should not have to type a number in.

## What's already set

| | |
|---|---|
| Stack-up | JLCPCB **JLC04161H-7628**, 4 layer, 1.6 mm. L1 signal / **L2 solid GND** / **L3 power (free)** / L4 signal |
| Impedance reference | 0.2104 mm of 7628 prepreg, Er 4.4, from L1 down to the L2 ground plane |
| Zones | GND on **F.Cu, In1.Cu, B.Cu**. **In2.Cu is left free** — it is the power layer |
| Net classes | assigned automatically by name — see below |
| DRC limits | set to JLCPCB's real capability, not a house style. DRC complains only if the fab would |

## Net classes (applied by pattern, nothing to select)

| Class | Nets | Track | Clearance | Via | Diff pair |
|---|---|---|---|---|---|
| **MIPI_100R** | `CSI_*` | 0.22 | 0.18 | 0.45/0.25 | **0.22 W / 0.18 gap** → 100 Ω |
| **USB_90R** | `USB_D*` | 0.27 | 0.18 | 0.45/0.25 | **0.27 W / 0.18 gap** → 90 Ω |
| **Power** | `+5V` `+3V3` `+1V8` `GND` `VBUS_IN` | 0.5 | 0.2 | 0.9/0.4 | – |
| Default | everything else | 0.2 | 0.15 | 0.6/0.3 | – |

Select a pair and use **Route → Differential Pair (6)**; KiCad picks the width and gap
from the class. `Ctrl+Shift+H` while routing swaps sides.

## DRC constraints = JLCPCB capability

| Constraint | Set to | Why |
|---|---|---|
| Min track / clearance | 0.09 / 0.09 mm | JLCPCB 4-layer, 1 oz outer |
| Min via diameter / drill | 0.25 / 0.15 mm | their absolute minimum (costs extra below 0.45/0.25) |
| Min annular ring | 0.13 mm | |
| Min hole-to-hole | 0.20 mm | |
| Copper to board edge | 0.20 mm | |

The dropdowns are pre-loaded with 0.15 / 0.2 / 0.22 / 0.27 / 0.3 / 0.4 / 0.5 / 0.8 / 1.0 mm
tracks and 0.6/0.3, 0.45/0.25, 0.9/0.4 vias, so you can pick rather than type.

## The power layer (In2.Cu)

In2.Cu has **no zone on it** on purpose. It is yours to carve into rails.

To make a power island: switch to In2.Cu, `Ctrl+Shift+Z` (Add Filled Zone), draw the
outline, pick the net (`+5V`, `+3V3`, `+1V8`), and set **Priority 2**. If you later want
GND filling the leftovers on that layer, add a GND zone over the whole layer at
**Priority 0** — higher priority fills first, so the rails win and GND flows around them.

**Vias must be placed while routing, not standalone.** Start a track from the pad, press
**`V`** mid-route: the via inherits the net and drops you onto the other layer. A via
placed on its own with the via tool has no net, and nothing will connect to it.

### Zones and vias — how the connection actually happens

A zone bonds to pads and vias **that are already on its net**, and carves a clearance
moat around everything else. It does not hand its net to whatever lands inside it.
So the workflow is: route +5V on F.Cu, press `V` to drop a via (the via inherits +5V),
and where it lands inside the +5V pour on In2.Cu it bonds automatically — no track needed
on the inner layer. A via with no net just gets a hole cut around it.

Three things to remember:
- **Press `B` to fill zones.** An unfilled zone connects nothing and DRC will show the
  pads unconnected. Zones do not auto-fill on save.
- **Priority decides overlaps.** Higher fills first. Rails at priority 2, a GND
  catch-all at priority 0, and ground flows around the rails instead of over them.
- **Via current:** a 0.3 mm drill with 20 µm plating carries ~**1.5 A** at 10 °C rise.
  The module draws ~0.6 A, so one via is enough — use two for margin and redundancy.

**In1.Cu stays solid GND.** It is the reference plane for every controlled-impedance trace
on F.Cu. Cutting a slot in it under a MIPI pair breaks the return path — that is the
classic reason a camera link works on the bench and fails at temperature.

## Suggested order

1. **MIPI first — CSI_CLK, CSI_D0, CSI_D1** (U1 pads 7–12 ↔ J3 pins 2,3,5,6,8,9).
   Route as differential pairs on **F.Cu only**, no vias, straight across to the FPC.
   They are the reason the board is 4-layer; give them the clean space first.
2. **USB — USB_DP/DM** (U2 ↔ U1 pads 22/23), and USB_DP_CON/DM_CON (J1 ↔ U2).
   Pair, F.Cu, keep U2 in line between connector and module.
3. **Power** — VBUS_IN → F1 → +5V → U1 pads 79/80/81; then +3V3 from pad 78 out to
   J2, J3, H1, C3–C6; +1V8 from pad 77 to R5/R6 and J3 pin 21.
4. **Everything else** — SD bus, UART, I²C, reset, LED, VBUS_DET, recovery. Any layer.
5. **GND last** — poured on F.Cu, In1.Cu and B.Cu, so mostly you are adding stitching
   vias, not tracks. Drop a via next to each GND pad that isn't already touching a pour.

## The rules that actually matter

**MIPI (D-PHY, ~1 Gb/s per lane)**
- Intra-pair skew ≤ **0.1 mm**. Inter-pair (lane-to-lane, lane-to-clock) ≤ **1.0 mm**.
  Use *Route → Tune Differential Pair Skew* — the target lengths are in the class.
- **Never cross a gap in the L2 ground plane.** The return current follows the trace on
  L2; a split under a pair is the classic MIPI failure.
- No vias, no stubs, no test points on the pairs. If you must change layer, both legs
  change at the same point and you add a ground via beside them.
- Keep ≥ 0.55 mm (3× the gap) from any other signal.

**USB 2.0** — same idea, looser. Pair length match ≤ 1.0 mm, keep U2 within ~5 mm of J1.

**Power** — 0.5 mm carries **1.44 A** on an outer layer at 10 °C rise (IPC-2221, 1 oz).
The module draws roughly 0.6 A, so 0.5 mm is ~2.4× margin; 0.3 mm would still do.
Put the +5 V bulk cap C1 between F1 and the module pads, not off to one side.

**Under the module** — Luckfox's own footprint carries keep-out rings; don't put copper
in them. The area inside is otherwise usable, but keeping F.Cu clear under the middle of
the module is tidier, and B.Cu underneath is completely free.

## Done when

DRC reports **0 unconnected**, 0 clearance errors. Expect a handful of silkscreen
warnings near the board edge and a "footprint library not enabled" note for Core1106 —
both cosmetic.

Two offline checkers in this folder, independent of KiCad:

    python3 continuity.py                 # per-net island count + missing connections
    python3 continuity.py --clearance     # also test net-to-net spacing (slower)
    python3 continuity.py --fine          # 0.02 mm grid instead of 0.05

`continuity.py` rasterises all copper — pads, tracks, vias and *filled* zones — joins
layers through vias, and counts how many electrically separate islands each net forms.
**1 island = that net is fully connected.** N islands means N−1 connections still missing.
It tells you *how far* a net is from done, which the ratsnest does not.

Fill your zones (`B`) and save before running it, or pours are ignored and GND will
look disconnected.

`check.py` is the older clearance-only version; `continuity.py` supersedes it.

## If you want the parts somewhere else

Placement lives in `placement.py` — `ref: (x, y, rotation)` in mm, board origin top-left.
Change it and run `python3 genpcb.py` to rebuild the board. Or just drag parts in KiCad;
nothing downstream depends on where they sit.

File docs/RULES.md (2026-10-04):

# LocalCam-1 PCB stack-up and design rules

## Stack-up: JLCPCB JLC04161H-7628 (4-layer, 1.6 mm)  — source: jlcpcb.com/impedance
| # | Layer | Material | Thickness | Er | Role |
|---|---|---|---|---|---|
| L1 | F.Cu | Cu 1 oz | 0.035 mm | – | Signals: MIPI pairs, USB pair, all components |

Seven copper+dielectric rows sum to **1.5862 mm**, matching JLCPCB's stackup table exactly; KiCad shows 1.6062 mm because it also counts the two 0.01 mm solder masks.

| – | Prepreg 7628 | FR-4 | 0.2104 mm | 4.4 | |
| L2 | In1.Cu | Cu 0.5 oz | 0.0152 mm | – | **Solid GND** (reference for every L1 trace) |
| – | Core | FR-4 | **1.065 mm** | 4.6 | JLCPCB published value. Their "1.1 mm H/HOZ with copper" note is the core *plus* both inner foils — do not derive the dielectric from it. |
| L3 | In2.Cu | Cu 0.5 oz | 0.0152 mm | – | Power pours: +5V, +3V3, +1V8 islands, GND fill |
| – | Prepreg 7628 | FR-4 | 0.2104 mm | 4.4 | |
| L4 | B.Cu | Cu 1 oz | 0.035 mm | – | GND fill, slow signals only if needed |

## Controlled-impedance geometry (L1 over L2, IPC-2141 coupled microstrip; solder mask lowers ~3-5%, so targets sit slightly high)
| Net class | Target | Width | Gap | Model |
|---|---|---|---|---|
| MIPI_100R (`CSI_*`) | 100 Ω diff | 0.22 mm | 0.18 mm | 103 Ω |
| USB_90R (`USB_D*`) | 90 Ω diff | 0.27 mm | 0.18 mm | 91 Ω |
| 50 Ω single-ended (none required) | 50 Ω | 0.35 mm | – | 50 Ω |
**Final widths are confirmed in JLCPCB's impedance calculator at order time**; with "impedance control" ticked, JLCPCB tunes widths to the measured stack. Never route a controlled pair over an L2 gap.

## MIPI CSI-2 (D-PHY) routing rules
- Lanes: CLK, D0, D1 on L1 only, no layer change between module and J3 (short, <40 mm expected).
- Intra-pair skew ≤ 0.1 mm (≈ 0.7 ps). Inter-pair (lane-to-lane and lane-to-clock) ≤ 1.0 mm.
- Keep ≥ 3× gap (0.55 mm) from other signals; ground on both sides of the FPC connector pairs already in the pinout.
- No stubs, no test points on pairs.

## USB 2.0 rules
- Pair on L1, ESD part U2 in-line within 5 mm of J1, pair length match ≤ 1.0 mm.

## Fab limits used (JLCPCB 4-layer, 1 oz outer) — source: jlcpcb.com/capabilities/pcb-capabilities
| Rule | JLCPCB minimum | Design value used |
|---|---|---|
| Track width / spacing | 0.09 / 0.09 mm | **0.15 / 0.15 mm** default; 0.127 allowed near fine-pitch |
| Via hole / diameter | 0.15 / 0.25 mm | **0.30 / 0.70 mm** |
| Annular ring | 0.20 mm | 0.20 mm ((0.70−0.30)/2) |
| Copper to board edge | 0.20 mm | **0.30 mm** |
| Hole to hole | 0.20 mm (via) | 0.25 mm |
| Solder-mask bridge | 0.20 mm | default |
| Power tracks | – | +5V/+3V3 ≥ 0.50 mm on L1; 1 mm where feasible |

## Assembly constraints (JLCPCB SMT, top side only)
- Passives 0603 preferred (Basic parts); 0402 acceptable where the KiCad footprint already is 0402 — decide per part in the BOM pass.
- Core1106 module hand-soldered after assembly (castellated). Keep 1.0 mm clear around it for iron access.
- Hirose FH12 FPC and HRO USB-C, DM3AT microSD: confirm LCSC stock in the BOM task; substitute compatible footprints if not.

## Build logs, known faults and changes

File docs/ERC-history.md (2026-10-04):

# LocalCam-1 Rev A — KiCad project

**Requires KiCad 8 or newer.** The schematic is written in KiCad 7 format (so 7/8/9 all
read it), but Luckfox's official Core1106 **footprint** is KiCad 8 format
(`version 20240108`) and will not load in KiCad 7.

**Validated with KiCad's own parser** (`kicad-cli sch export netlist`): the schematic
loads, and the netlist KiCad derives from it matches `spec.py` exactly — 36 nets,
28 components, every footprint assigned.

**`spec.py` is the source of truth.** It holds every part and every net.
`LocalCam1.kicad_sch` is a build output — regenerate it, don't hand-edit it:

    python3 gen.py

The schematic uses **global labels on every pin** rather than drawn wires, so it
is clean by construction: no junctions, no crossings, no floating segments.

## Design rules baked in
- The Core1106 has an **onboard PMIC**. Feed 5 V to `VCC5V0_SYS` (pads 79/80/81).
  `VCC_3V3` (78) and `VCC_1V8` (77) are **outputs** — never drive them. No external buck.
- Pads **37–46** (eMMC) and **48/63/68** (WiFi control) are used internally — do not route.
- Debug UART is **UART2 on the M1 mux** (pads 72/73); the M0 mux collides with the SD bus.
- Recovery is an ADC key on `SARADC_IN0` (pad 26), or `reboot loader` in software.
- microSD works, but card-detect (pad 48) is taken by the WiFi — mark the slot non-removable.
- J3 is our own camera FPC; grounds flank each differential pair.

## Net classes (pre-set in the .kicad_pro)
`MIPI_100R` for `CSI_*` (100 Ω differential) · `USB_90R` for `USB_D*` (90 Ω) ·
`Power` for the rails · `Default` for everything else.

## Audit findings applied (Rev A, pre-layout)
| # | Finding | Fix |
|---|---|---|
| 1 | Camera I²C pull-ups went to **+3V3**, but pads 13/14/15/18/19 are a **1.8 V IO bank** (VCCIO7, "1.8V only") — over-drives the inputs | R5/R6 now pull to **+1V8** (pad 77, a module output). `+1V8` also routed to J3-21 so the camera board shares one 1.8 V I/O reference |
| 2 | **USB_VBUSDET (pad 24) floating** — module cannot detect USB presence | R7/R8 100 k 2:1 divider from +5V into pad 24 (`VBUS_DET`) `[verify divider ratio vs RV1106 datasheet]` |
| 3 | `ADC0_RECOV` is a **1.8 V SARADC input** brought to a header next to +3V3 — over-voltage hazard | R9 1 k in series (`RECOV_HDR` on the header) |
| 4 | TVS **SMAJ5.0CA**: V_RWM = 5.0 V vs VBUS max 5.25 V — sits in the leakage knee at normal operating voltage | **SMAJ6.0CA** (V_RWM 6.0 V > 1.05 × 5.25 = 5.51 V) |
| 5 | No decoupling on **+3V3** at the FPC, or at the **microSD** VDD | C3/C4 (10 µF + 100 nF) at J3; C5/C6 at J2 |
| 6 | Bulk **10 µF** gives ~2 V droop for a 0.4 A WiFi TX step over 50 µs | C1 → **47 µF** (~430 mV; add more if bring-up shows brownouts) |
| 7 | LED resistor 1 k → 0.3 mA with a green/blue LED (invisible) | **330 R** + red LED specified (~4 mA) |

### Confirmed correct (no change)
- **5.1 kΩ ×2 CC pulldowns**, one per CC pin — USB Type-C R2.0 Table 4-25 Rd for a sink.
- **4.7 kΩ I²C pull-ups**: t_r = 119–199 ns at 30–50 pF, inside the 300 ns fast-mode limit; R_min at 1.8 V is 533 Ω, so 4.7 k is safe.
- **3V3 budget**: 0.26 A external + ~0.3 A RV1106 IO = 0.56 A against the module buck's ~1.6 A → 2.9× margin.
- **Polyfuse 1.5 A hold**: load ~0.79 A at 5 V; derated 1.08 A at 60 °C (1.4×). Marginal at 85 °C — if the enclosure runs hotter, move to 2.0 A.

## ERC log

| Run | Tool | Errors | Warnings | Notes |
|---|---|---|---|---|
| Rev A.0 | KiCad 10.0 GUI | 78 | 170 | 69 x pin_not_connected (all deliberately unused pads, verified against spec.py), 7 x pin_not_driven (same pins), 2 x power_pin_not_driven (J2 VDD/VSS - no power-output on rails), 167 x endpoint_off_grid (metric origins vs 50 mil grid), 3 x lib_symbol_mismatch (KiCad 7 libs vs 10) |
| Rev A.1 | generated | - | - | Fixes: PWR_FLAG on +5V/+3V3/+1V8/GND; part origins snapped to 1.27 mm; explicit no_connect on all 69 unused pins. Netlist re-verified against spec.py via kicad-cli (36/36 nets match). |
| Rev A.1 | KiCad 10.0 GUI | 2 | 3 | 2 x Output+PowerOutput conflict (U1 77/78 typed "output" by Luckfox vs my PWR_FLAG) ; 3 x lib_symbol_mismatch (cosmetic, KiCad 7 vs 10 stock libs) |
| Rev A.2 | generated | - | - | lib/Core1106.kicad_sym pins 76/77/78 -> power_out, 79/80/81 -> power_in (patch_core1106.py). PWR_FLAG kept only on +5V and GND. Netlist re-verified 36/36. |
| Rev A.2 | KiCad 10.0 GUI | 1 | 3 | PowerOutput+PowerOutput: U1 76 (VCC3V3_RTC) tied to U1 78 (VCC_3V3) in spec. |
| Rev A.3 | generated | - | - | **Spec error fixed.** Module schematic (PART A) shows VCC_3V3 -> D1 RB521S-30 -> pad 76 -> R14 100R -> RTC_AVDD3V3. Pad 76 is the RTC backup-battery tap, not a supply; tying it to +3V3 shorted across D1. Now NC (passive). Future: coin cell / supercap on pad 76 for RTC hold-up. Netlist re-verified 36/36. |

### Audit addendum (Rev A.3)
| # | Finding | Severity | Source | Fix |
|---|---|---|---|---|
| A-7 | Pad 76 VCC3V3_RTC was on +3V3, shorting the module's RTC isolation diode D1 | Medium (defeats backup design; no damage) | Core1106 schematic PART A, D1/R14/C26 | Pad 76 -> NC in spec.py; documented as future backup tap |
| Rev A.3 | KiCad 10.0 GUI | 0 | 3 | lib_symbol_mismatch x3 (J1, J2, D2): generated from KiCad 7 stock libs. |
| Rev A.4 | generated | - | - | Generator now reads the workstation's KiCad 10.0 stock libraries and emits the native 20260101 dialect. KiCad 10 renamed shield pins: J1 S1->SH, J2 9->SH (footprints match). verify10.py rebuilds the netlist from file geometry alone: 36/36 nets, 216/216 pins accounted for. |
| Rev A.5 | generated | - | - | **A-8**: camera I2C moved from pads 14/15 (I2C3_M2) to 16/17 (I2C4_M2), which Luckfox's module schematic labels MIPI_I2C and their stock camera DTS expects. Pads 14/15 now NC. Pad 24 (USB_VBUSDET) confirmed 3.3 V domain per PinOut.xls, so the 2.5 V divider is in range. See MECH.md. |

## Phase 2 - PCB

Board 75 x 44 mm, 4-layer (JLCPCB JLC04161H-7628), 4 x M2 holes. Generated by `genpcb.py`
(placement, from `placement.py`) then `route.py` (autorouted). `check.py` is the independent
geometric oracle: it rasterises every pad/track/via at 0.02 mm and reports any pair of
different nets closer than the clearance.

| Stage | Result |
|---|---|
| Placement | 32 footprints, no courtyard overlaps |
| Routing | 52/52 connections, 1267 segments, 87 vias |
| GND | 49 pads stitched to the In1.Cu plane; the rest connect through the F.Cu pour |
| check.py | **0 clearance violations** at 0.02 mm resolution |
| Left for interactive routing | `CSI_CLK/D0/D1` pairs, `USB_DP/DM` - net classes preset (100R: 0.22/0.18, 90R: 0.27/0.18) |

Design choices the router enforces:
- F.Cu is kept clear under the centre of the module (inside Luckfox's keep-out rings); a
  ~4 mm annulus inside the pad ring is used for escape routing. B.Cu underneath is free.
- Signals 0.15 mm (needed to escape the 0.5 mm-pitch FPC and USB-C), +3V3 0.4 mm,
  +5V/VBUS_IN 0.5 mm, +1V8 0.3 mm.
- Every GND pad gets its own via to the ground plane where there is room for one.

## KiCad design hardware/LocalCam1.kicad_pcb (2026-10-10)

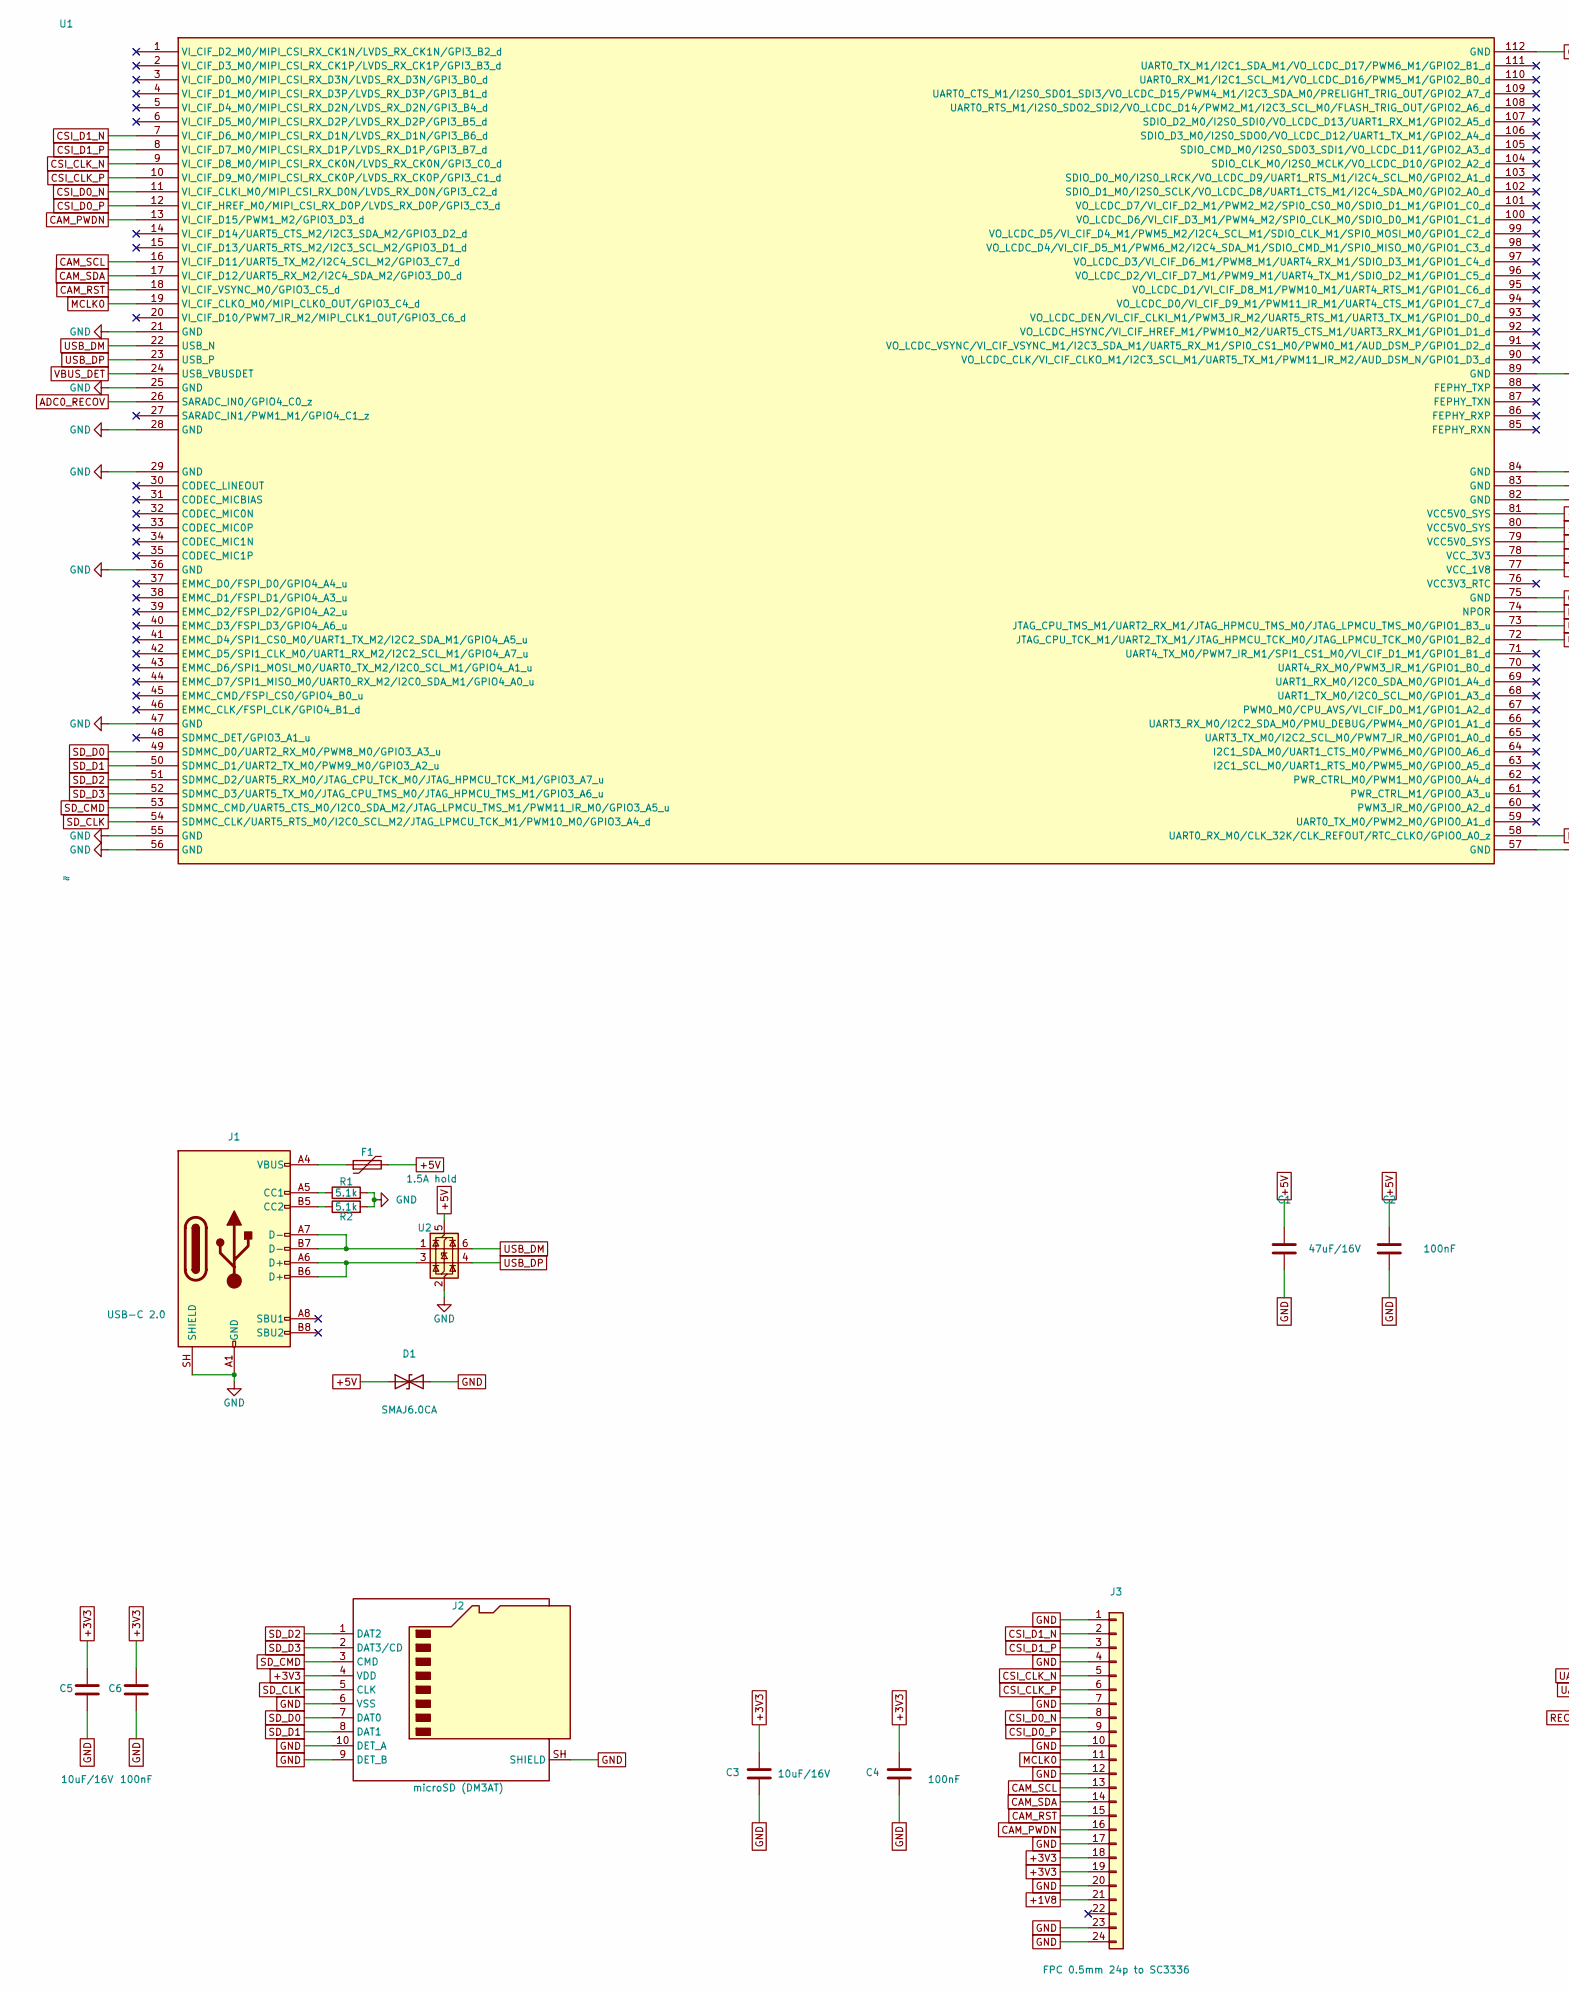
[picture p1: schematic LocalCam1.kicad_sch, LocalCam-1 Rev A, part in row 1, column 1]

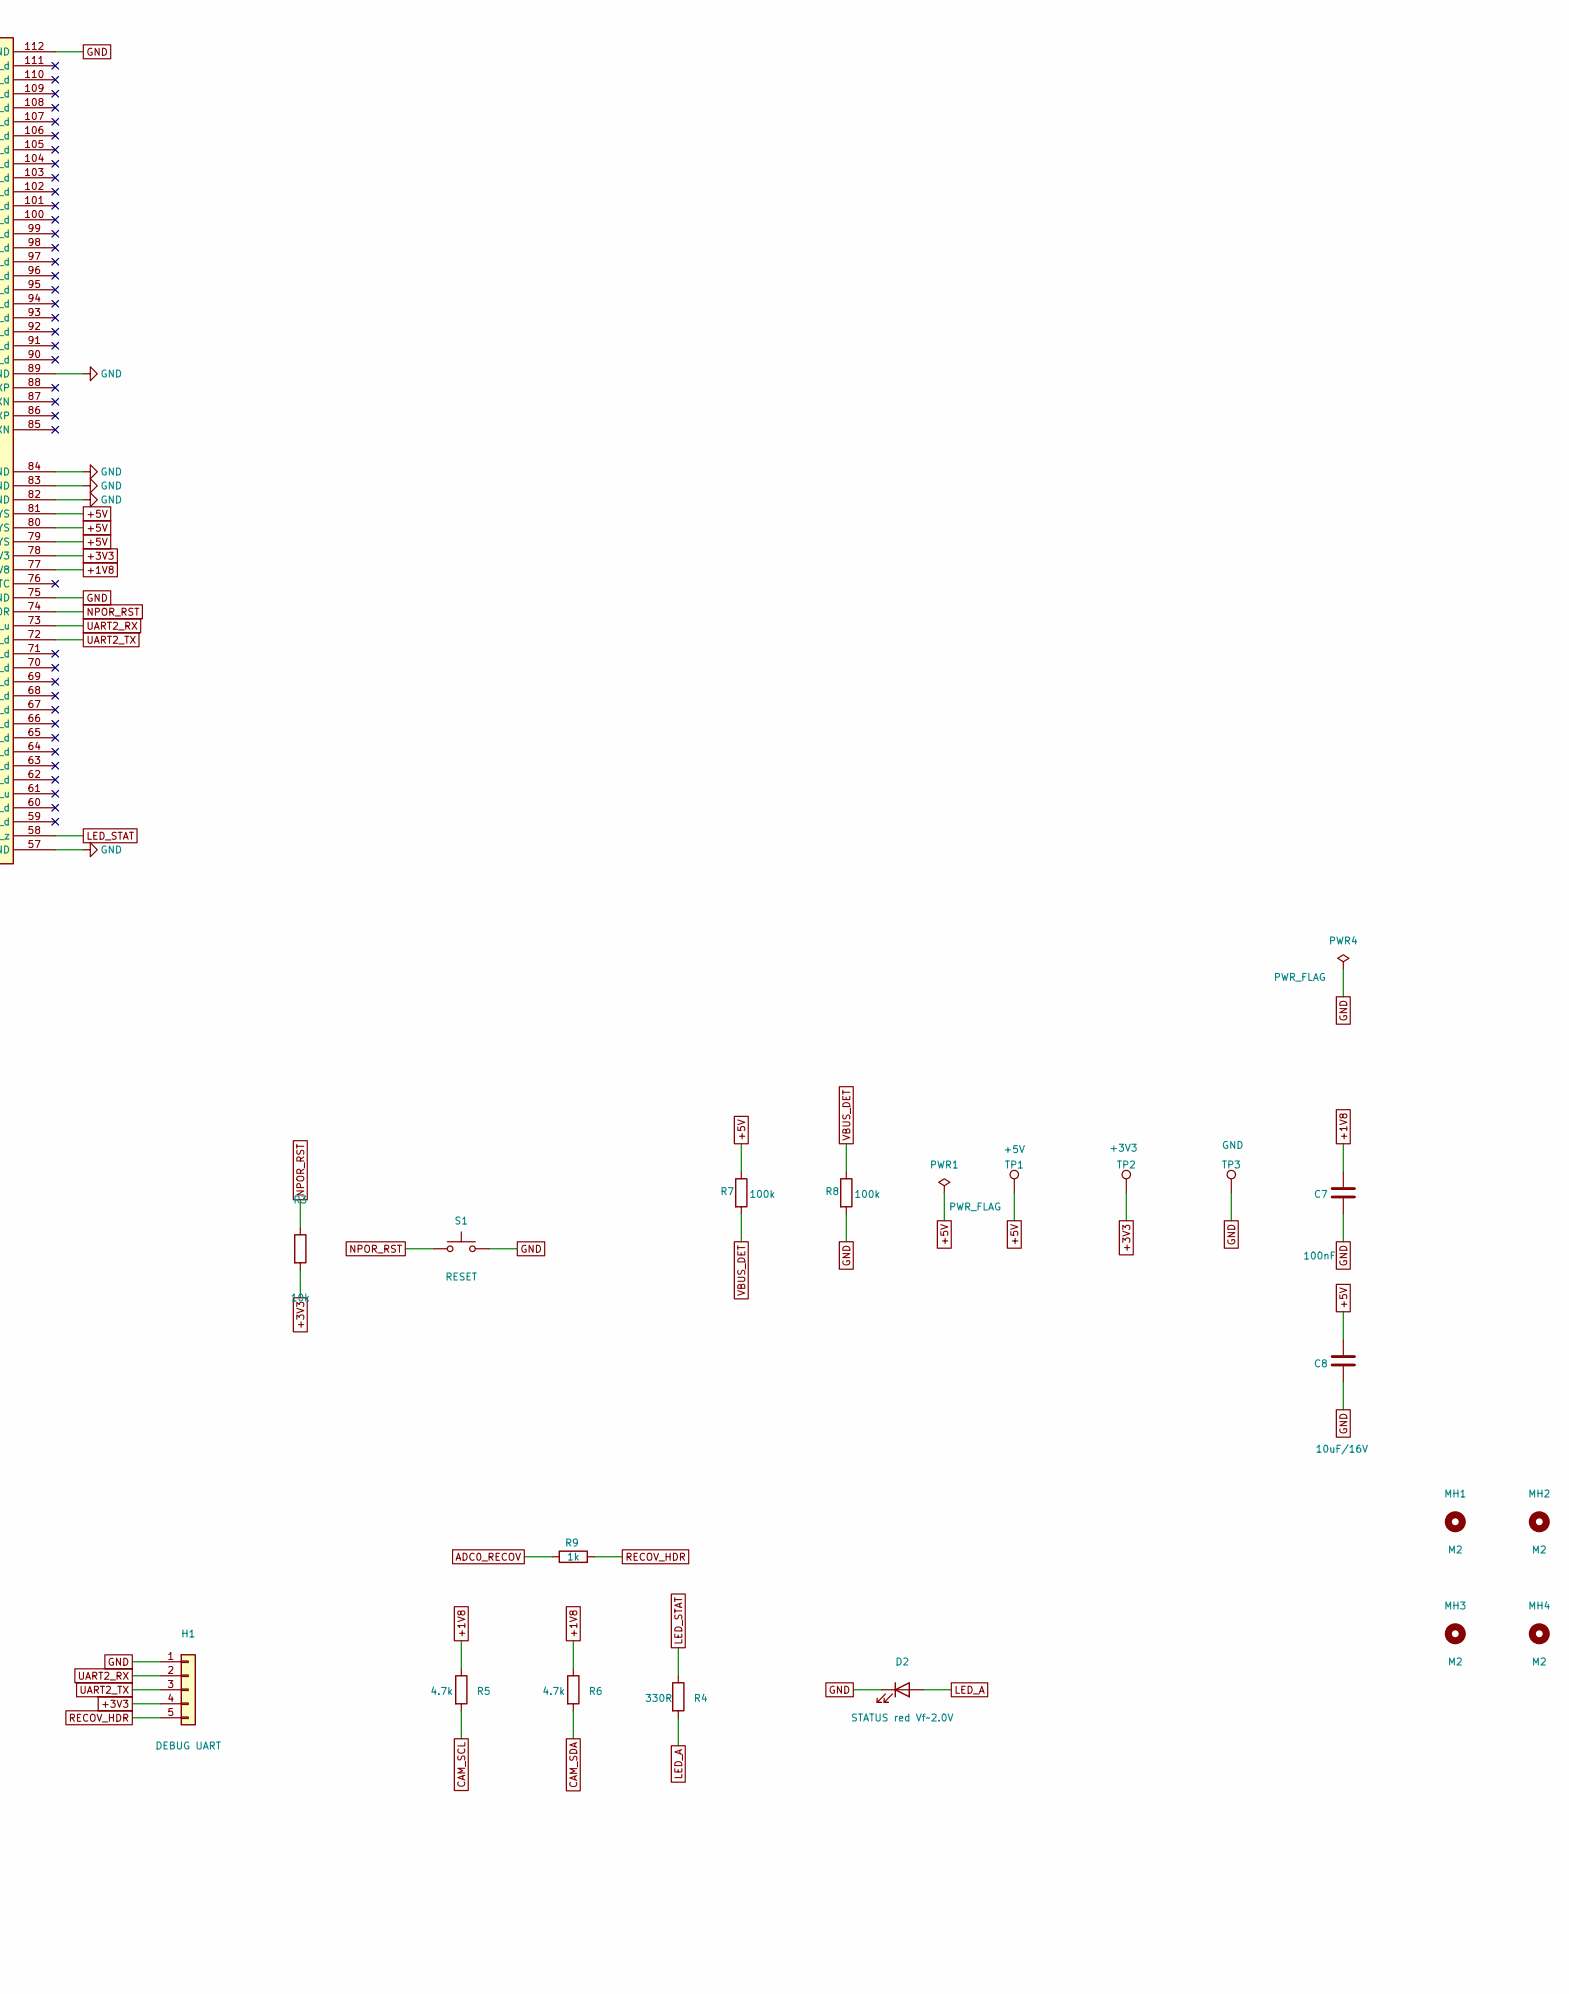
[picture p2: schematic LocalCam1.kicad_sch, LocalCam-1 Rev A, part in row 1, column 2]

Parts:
C1: 47uF/16V; C_0805_2012Metric
C2, C4, C6, C7: 100nF; C_0402_1005Metric
C3, C5, C8: 10uF/16V; C_0805_2012Metric
D1: SMAJ6.0CA; D_SMA
D2: STATUS red Vf~2.0V; LED_0603_1608Metric
F1: 1.5A hold; R_1206_3216Metric
H1: DEBUG UART; PinHeader_1x05_P2.54mm_Vertical
J1: USB-C 2.0; USB_C_Receptacle_HRO_TYPE-C-31-M-12
J2: microSD (DM3AT); microSD_HC_Hirose_DM3AT-SF-PEJM5
J3: FPC 0.5mm 24p to SC3336; Hirose_FH12-24S-0.5SH_1x24-1MP_P0.50mm_Horizontal
MH1, MH2, MH3, MH4: M2; MountingHole_2.2mm_M2
PWR1, PWR4: PWR_FLAG
R1, R2: 5.1k; R_0402_1005Metric
R3: 10k; R_0402_1005Metric
R4: 330R; R_0402_1005Metric
R5, R6: 4.7k; R_0402_1005Metric
R7, R8: 100k; R_0402_1005Metric
R9: 1k; R_0402_1005Metric
S1: RESET; SW_Push_1P1T_NO_CK_KMR2
TP1: +5V; TestPoint_Pad_D1.5mm
TP2: +3V3; TestPoint_Pad_D1.5mm
TP3: GND; TestPoint_Pad_D1.5mm
U1: ≈; Core1106-SMT
U2: USBLC6-2SC6; SOT-23-6

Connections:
+1V8: C7.1, J3.21, R5.1, R6.1, U1.77 (VCC_1V8)
+3V3: C3.1, C4.1, C5.1, C6.1, H1.4, J2.4 (VDD), J3.18, J3.19, R3.2, TP2.1, U1.78 (VCC_3V3)
+5V: C1.1, C2.1, C8.1, D1.1 (A1), F1.2, PWR1.1, R7.1, TP1.1, U1.79 (VCC5V0_SYS), U1.80 (VCC5V0_SYS), U1.81 (VCC5V0_SYS), U2.5 (VBUS)
ADC0_RECOV: R9.1, U1.26 (SARADC_IN0/GPIO4_C0_z)
CAM_PWDN: J3.16, U1.13 (VI_CIF_D15/PWM1_M2/GPIO3_D3_d)
CAM_RST: J3.15, U1.18 (VI_CIF_VSYNC_M0/GPIO3_C5_d)
CAM_SCL: J3.13, R5.2, U1.16 (VI_CIF_D11/UART5_TX_M2/I2C4_SCL_M2/GPIO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)
CAM_SDA: J3.14, R6.2, U1.17 (VI_CIF_D12/UART5_RX_M2/I2C4_SDA_M2/GPIO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)
CC1: J1.A5 (CC1), R1.1
CC2: J1.B5 (CC2), R2.1
CSI_CLK_N: J3.5, U1.9 (VI_CIF_D8_M0/MIPI_CSI_RX_CK0N/LVDS_RX_C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)
CSI_CLK_P: J3.6, U1.10 (VI_CIF_D9_M0/MIPI_CSI_RX_CK0P/LVDS_RX_C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)
CSI_D0_N: J3.8, U1.11 (VI_CIF_CLKI_M0/MIPI_CSI_RX_D0N/LVDS_RX_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)
CSI_D0_P: J3.9, U1.12 (VI_CIF_HREF_M0/MIPI_CSI_RX_D0P/LVDS_RX_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)
CSI_D1_N: J3.2, U1.7 (VI_CIF_D6_M0/MIPI_CSI_RX_D1N/LVDS_RX_D1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)
CSI_D1_P: J3.3, U1.8 (VI_CIF_D7_M0/MIPI_CSI_RX_D1P/LVDS_RX_D1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)
GND: C1.2, C2.2, C3.2, C4.2, C5.2, C6.2, C7.2, C8.2, D1.2 (A2), D2.1 (K), H1.1, J1.A1 (GND), J1.A12 (GND), J1.B1 (GND), J1.B12 (GND), J1.SH (SHIELD), J2.6 (VSS), J2.9 (DET_B), J2.10 (DET_A), J2.SH (SHIELD), J3.1, J3.4, J3.7, J3.10, J3.12, J3.17, J3.20, J3.23, J3.24, PWR4.1, R1.2, R2.2, R8.2, S1.2, TP3.1, U1.21 (GND), U1.25 (GND), U1.28 (GND), U1.29 (GND), U1.36 (GND), U1.47 (GND), U1.55 (GND), U1.56 (GND), U1.57 (GND), U1.75 (GND), U1.82 (GND), U1.83 (GND), U1.84 (GND), U1.89 (GND), U1.112 (GND), U2.2 (GND)
LED_A: D2.2 (A), R4.2
LED_STAT: R4.1, U1.58 (UART0_RX_M0/CLK_32K/CLK_REFOUT/RTC_CLKO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)
MCLK0: J3.11, U1.19 (VI_CIF_CLKO_M0/MIPI_CLK0_OUT/GPIO3_C4_d)
NPOR_RST: R3.1, S1.1, U1.74 (NPOR)
RECOV_HDR: H1.5, R9.2
SD_CLK: J2.5 (CLK), U1.54 (SDMMC_CLK/UART5_RTS_M0/I2C0_SCL_M2/JTAG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)
SD_CMD: J2.3 (CMD), U1.53 (SDMMC_CMD/UART5_CTS_M0/I2C0_SDA_M2/JTAG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)
SD_D0: J2.7 (DAT0), U1.49 (SDMMC_D0/UART2_RX_M0/PWM8_M0/GPIO3_A3_u)
SD_D1: J2.8 (DAT1), U1.50 (SDMMC_D1/UART2_TX_M0/PWM9_M0/GPIO3_A2_u)
SD_D2: J2.1 (DAT2), U1.51 (SDMMC_D2/UART5_RX_M0/JTAG_CPU_TCK_M0/JT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)
SD_D3: J2.2 (DAT3/CD), U1.52 (SDMMC_D3/UART5_TX_M0/JTAG_CPU_TMS_M0/JT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)
UART2_RX: H1.2, U1.73 (JTAG_CPU_TMS_M1/UART2_RX_M1/JTAG_HPMCU_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)
UART2_TX: H1.3, U1.72 (JTAG_CPU_TCK_M1/UART2_TX_M1/JTAG_HPMCU_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)
USB_DM: U1.22 (USB_N), U2.6 (I/O1)
USB_DM_CON: J1.A7 (D-), J1.B7 (D-), U2.1 (I/O1)
USB_DP: U1.23 (USB_P), U2.4 (I/O2)
USB_DP_CON: J1.A6 (D+), J1.B6 (D+), U2.3 (I/O2)
VBUS_DET: R7.2, R8.1, U1.24 (USB_VBUSDET)
VBUS_IN: F1.1, J1.A4 (VBUS), J1.A9 (VBUS), J1.B4 (VBUS), J1.B9 (VBUS)

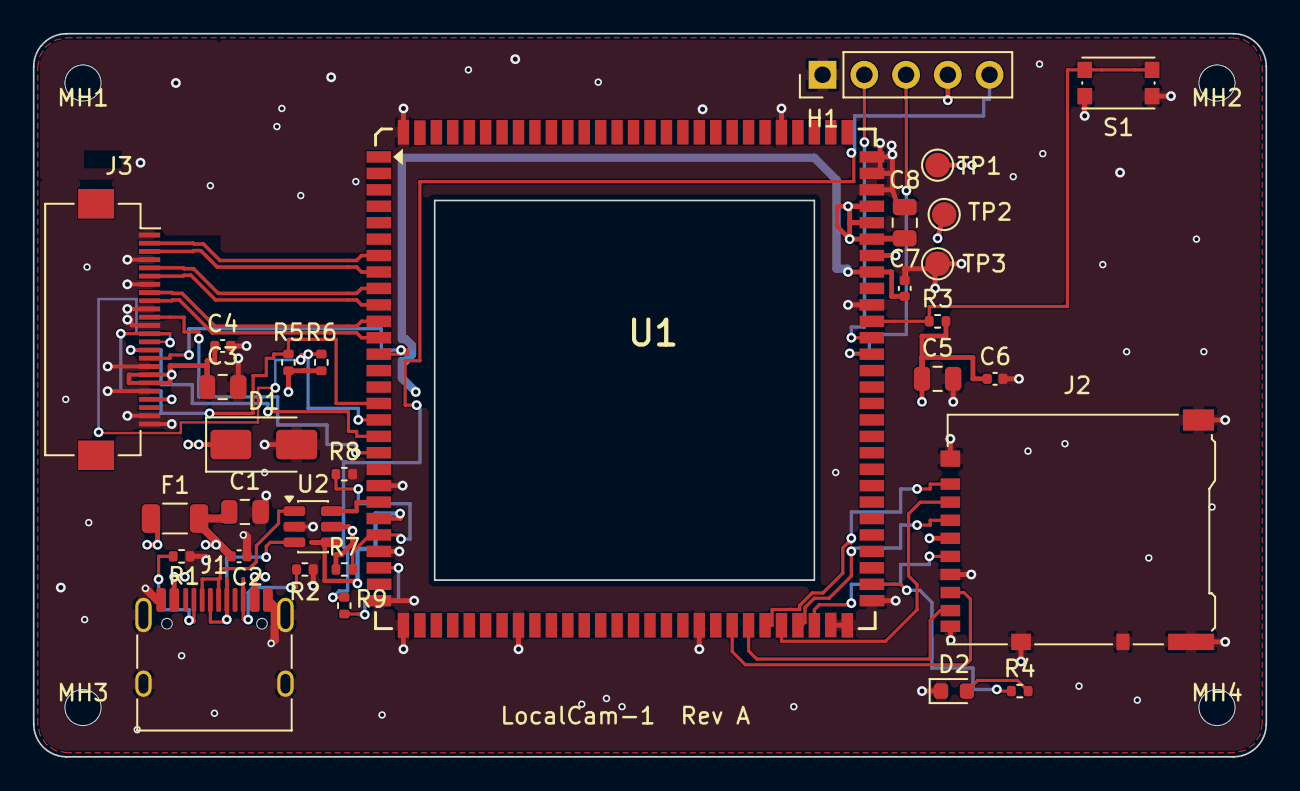
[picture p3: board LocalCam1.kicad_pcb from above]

Board: 4 copper layers, 75.0 x 44.0 mm, 34 parts (0 on the bottom side), 36 nets.

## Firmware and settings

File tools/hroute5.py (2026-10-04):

"""LocalCam-1 router v2 -- rebuilt after DFM review found the v1 architecture unsound.

What v1 got wrong and this fixes:
  * v1's clear_path() returned True for any layer not in its 2-layer table, so the
    whole In2.Cu power layer was routed with collision detection OFF (+5V/+3V3/+1V8
    ended up shorted).  Occupancy here covers all four copper layers.
  * v1 would pick B.Cu for a net whose pads are top-side SMD and never add a via,
    leaving the trace floating.  Here a route always begins and ends on a layer the
    pad actually reaches; any layer change is an explicit, collision-checked via.
  * v1 dropped power and stitching vias with no test at all.  can_via() gates every one.
  * v1 exempted a diff-pair partner from clearance entirely.  Here the partner is
    routed against a relaxed mask, then the real polyline-to-polyline distance is
    measured and the route is rejected if it is under the designed gap.
  * v1's connect() returned True whenever it laid metal, so the log said OK for nets
    with no copper.  Here every net is island-checked at the end and the build FAILS
    on any net that is not electrically whole.

Style rules kept from v1 (this is the point of the exercise):
  45 deg geometry only, F.Cu trends horizontal / B.Cu vertical, perpendicular pad
  escapes, clean L/Z shapes preferred over search, rails daisy-chained as a spine.
"""
import sys, os, re, math, heapq, uuid, time
import numpy as np
from scipy import ndimage
sys.path.insert(0, '/home/claude')
from sexp import parse, find, val, unq

SRC, DST = sys.argv[1], sys.argv[2]
G     = 0.05      # 0.1 mm quantised a legal 0.35 mm gap down to 0.30 and failed it
LAYERS = ['F.Cu', 'In1.Cu', 'In2.Cu', 'B.Cu']
LI    = {n: i for i, n in enumerate(LAYERS)}
SIG   = ['F.Cu', 'B.Cu']
PWR_L = 'In2.Cu'
PREF  = {'F.Cu': 'h', 'B.Cu': 'v', 'In2.Cu': 'h', 'In1.Cu': 'h'}
CLR   = {'MIPI': 0.18, 'USB': 0.18, 'PWR': 0.2, 'DEF': 0.15}
WID   = {'MIPI': 0.22, 'USB': 0.27, 'PWR': 0.5, 'DEF': 0.2}
GAP   = {'MIPI': 0.18, 'USB': 0.18}
PITCH = {'MIPI': 0.40, 'USB': 0.45}
VIA_D, VIA_DRL = 0.6, 0.3
# Board style is strictly orthogonal: every trace parallel or perpendicular to an edge.
# The one exception is the three camera pairs, where a square corner needs so much more
# lateral room in the shared FPC channel that the clock pair cannot stay coupled -- and
# 3 mm of intra-pair skew on a MIPI clock is a dead camera.  DIAG is true only there.
DIAG = [False]
ESC   = 0.6
NS    = uuid.UUID('6f1c2a44-3b7e-4d1a-9c55-0a1b2c3d4e5f')
_uc = {}
def UD(k):
    _uc[k] = _uc.get(k, 0) + 1
    return str(uuid.uuid5(NS, f'{k}#{_uc[k]}'))

src = open(SRC).read()
def strip(txt, tag):
    n = 0
    while True:
        m = re.search(r'\n\t\(' + tag + r'\b', txt)
        if not m: break
        d = 0; j = m.start()+1
        while True:
            if txt[j] == '(': d += 1
            elif txt[j] == ')':
                d -= 1
                if d == 0: break
            j += 1
        txt = txt[:m.start()] + txt[j+1:]; n += 1
    return txt, n
src, n1 = strip(src, 'segment'); src, n2 = strip(src, 'via')
# stale zone fills must go -- KiCad recomputes them, and plotting the old ones
# would bury signal traces inside the pours
nfill = len(re.findall(r'\(filled_polygon', src))
while True:
    m = re.search(r'\n\t+\(filled_polygon', src)
    if not m: break
    d = 0; j = m.start()+1
    while True:
        if src[j] == '(': d += 1
        elif src[j] == ')':
            d -= 1
            if d == 0: break
        j += 1
    src = src[:m.start()] + src[j+1:]
print(f'ripped up {n1} segments, {n2} vias, {nfill} stale zone fills')
bd = parse(src)

BW = BH = 0
for l in find(bd, 'gr_line'):
    for k in ('start','end'):
        a = find(l,k)[0]; BW = max(BW,float(a[1])); BH = max(BH,float(a[2]))
NX, NY = int(BW/G)+2, int(BH/G)+2
nets = sorted(set(re.findall(r'\(net "([^"]*)"\)', src)))
nidx = {n: i+1 for i, n in enumerate(nets)}
def xf(X,Y,r,x,y):
    t = math.radians(r); return (X+x*math.cos(t)+y*math.sin(t), Y-x*math.sin(t)+y*math.cos(t))

PADS = []
for fp in find(bd,'footprint'):
    at = find(fp,'at')[0]; X,Y = float(at[1]),float(at[2]); r = float(at[3]) if len(at)>3 else 0
    ref = [unq(p[2]) for p in find(fp,'property') if unq(p[1])=='Reference'][0]
    for p in find(fp,'pad'):
        a = find(p,'at')[0]; sz = find(p,'size')[0]
        nn = find(p,'net'); net = unq(nn[0][1]) if nn else None
        px,py = xf(X,Y,r,float(a[1]),float(a[2]))
        lays = [unq(z) for z in find(p,'layers')[0][1:]]
        thru = p[2] in ('thru_hole','np_thru_hole')
        on = LAYERS if thru or any(z=='*.Cu' for z in lays) else [z for z in LAYERS if z in lays]
        PADS.append(dict(ref=ref,pin=unq(p[1]),net=net,x=px,y=py,w=float(sz[1]),h=float(sz[2]),
                         rot=(float(a[3]) if len(a)>3 else 0),thru=thru,fx=X,fy=Y,on=on or ['F.Cu']))

ROWAX = {}; _br = {}
for _p in PADS: _br.setdefault(_p['ref'],[]).append(_p)
for _r,_ps in _br.items():
    _sx = max(q['x'] for q in _ps)-min(q['x'] for q in _ps)
    _sy = max(q['y'] for q in _ps)-min(q['y'] for q in _ps)
    ROWAX[_r] = None if len(_ps)<2 else ('v' if _sy>3*max(_sx,.01) else ('h' if _sx>3*max(_sy,.01) else None))

occ = [np.zeros((NX,NY),np.int32) for _ in LAYERS]
def box(arr,cx,cy,w,h,rot,v):
    if abs(rot)%180==90: w,h = h,w
    # +1, not +2: the slice end is exclusive, so +2 inflated every pad and track by
    # a full 0.1 mm cell on each side and made fine-pitch escapes look impossible.
    arr[max(0,int((cx-w/2)/G)):int((cx+w/2)/G)+1, max(0,int((cy-h/2)/G)):int((cy+h/2)/G)+1] = v
for p in PADS:
    v = nidx.get(p['net'],-1) if p['net'] else -1
    for ln in p['on']: box(occ[LI[ln]],p['x'],p['y'],p['w'],p['h'],p['rot'],v)
for a in occ:
    m = int(math.ceil(0.45/G)); a[:m,:]=-1; a[-m:,:]=-1; a[:,:m]=-1; a[:,-m:]=-1
for fp in find(bd,'footprint'):
    if 'Core1106' not in unq(fp[1]): continue
    at = find(fp,'at')[0]; X,Y = float(at[1]),float(at[2]); r = float(at[3]) if len(at)>3 else 0
    for z in find(fp,'zone'):
        if not find(z,'keepout'): continue
        pts = [xf(X,Y,r,float(q[1]),float(q[2])) for q in find(find(find(z,'polygon')[0],'pts')[0],'xy')]
        xs=[q[0] for q in pts]; ys=[q[1] for q in pts]
        for arr in occ: arr[max(0,int(min(xs)/G)):int(max(xs)/G)+2, max(0,int(min(ys)/G)):int(max(ys)/G)+2] = -1
    c0 = xf(X,Y,r,-10.6,-10.6); c1 = xf(X,Y,r,10.6,10.6)
    bx = sorted((c0[0],c1[0])); by = sorted((c0[1],c1[1]))
    occ[LI['F.Cu']][max(0,int(bx[0]/G)):int(bx[1]/G)+2, max(0,int(by[0]/G)):int(by[1]/G)+2] = -1
# In1.Cu is the solid ground plane: nothing but GND may live there
occ[LI['In1.Cu']][:,:] = np.where(occ[LI['In1.Cu']]==0, nidx['GND'], occ[LI['In1.Cu']])

# Union of every pad on the board, any net, grown by 0.1 mm.  A via may not overlap it:
# a via inside an SMD, FPC or castellated pad wicks paste during reflow, and JLCPCB
# does not do via-in-pad at this tier.  v3 dropped vias straight onto pad centres as a
# last resort, which put three of them inside pads.
PADMASK=np.zeros((NX,NY),bool)
for _p in PADS:
    _w,_h=_p['w']+0.2,_p['h']+0.2
    if abs(_p['rot'])%180==90: _w,_h=_h,_w
    PADMASK[max(0,int((_p['x']-_w/2)/G)):int((_p['x']+_w/2)/G)+1,
            max(0,int((_p['y']-_h/2)/G)):int((_p['y']+_h/2)/G)+1]=True

TRK=[]; VIAS=[]; _M={'_s':0}
VIAPOS=[]                      # every via centre, for the hole-to-hole rule
def lay_seg(x0,y0,x1,y1,ln,net,w):
    _M.clear(); _M['_s']=_M.get('_s',0)+1
    TRK.append((x0,y0,x1,y1,ln,net,w))
    n = max(2,int(max(abs(x1-x0),abs(y1-y0))/G)+2)
    for i in range(n+1):
        t=i/n; box(occ[LI[ln]],x0+(x1-x0)*t,y0+(y1-y0)*t,w,w,0,nidx[net])
def lay_via(x,y,net):
    _M.clear(); _M['_s']=_M.get('_s',0)+1
    VIAS.append((x,y,net)); VIAPOS.append((x,y))
    for arr in occ: box(arr,x,y,VIA_D,VIA_D,0,nidx[net])
# JLCPCB wants 0.20 mm hole to hole; two 0.3 mm drills put the centres 0.5 mm apart.
# 0.55 for margin, and it also stops the duplicate/co-located vias v3 emitted.
VIA_PITCH = 0.55
def can_via(x,y,net,clr=0.2):
    gx,gy = int(round(x/G)),int(round(y/G)); rad = int(math.ceil((VIA_D/2+clr)/G))
    if not (rad<=gx<NX-rad and rad<=gy<NY-rad): return False
    pr=int(math.ceil((VIA_D/2)/G))
    if PADMASK[gx-pr:gx+pr+1, gy-pr:gy+pr+1].any(): return False
    for vx,vy in VIAPOS:
        if abs(vx-x)<VIA_PITCH and abs(vy-y)<VIA_PITCH and math.hypot(vx-x,vy-y)<VIA_PITCH:
            return False
    for li,arr in enumerate(occ):
        # In1.Cu is a poured plane, not routed copper.  A foreign-net via passing
        # through it gets an antipad from the zone filler automatically, so plane
        # copper must not be treated as an obstacle -- v2 did, and that blocked
        # every non-GND via on the board.
        if LAYERS[li]=='In1.Cu': continue
        sub = arr[gx-rad:gx+rad+1, gy-rad:gy+rad+1]
        if np.any((sub!=0)&(sub!=nidx[net])): return False
    return True

def mask_for(ln,net,w,clr,ignore=None,box=None):
    """box = (x0,y0,x1,y1) in cells: dilate only that window.  A whole-board dilation
    at 0.05 mm is 1.3 M cells and is thrown away every time a segment is laid."""
    key=(ln,net,round(w,3),round(clr,3),ignore,box,_M.get('_s',0))
    if key in _M: return _M[key]
    arr=occ[LI[ln]]; rad=int(math.ceil((w/2+clr)/G)); v=nidx[net]
    st=np.ones((2*rad+1,2*rad+1),bool)
    if box is None:
        bad=(arr!=0)&(arr!=v)
        if ignore: bad &= (arr!=nidx[ignore])
        ok=~ndimage.binary_dilation(bad,structure=st)
    else:
        x0,y0,x1,y1=box
        sub=arr[x0:x1,y0:y1]
        bad=(sub!=0)&(sub!=v)
        if ignore: bad &= (sub!=nidx[ignore])
        ok=np.zeros((NX,NY),bool); ok[x0:x1,y0:y1]=~ndimage.binary_dilation(bad,structure=st)
    _M[key]=ok; return ok
def pad_rect(pad,m=0.10):
    w,h=pad['w'],pad['h']
    if abs(pad['rot'])%180==90: w,h=h,w
    return (pad['x'],pad['y'],w/2+m,h/2+m)
def in_rects(x,y,rects):
    for cx,cy,hw,hh in rects:
        if abs(x-cx)<=hw and abs(y-cy)<=hh: return True
    return False
def clear_path(pts,ln,net,w,clr,ok=None,ignore=None,exempt=None):
    """exempt: pad rectangles where clearance is not the trace's problem.  Leaving a
    0.5 mm-pitch FPC pad is physically impossible if the neighbouring pad's clearance
    halo is enforced over the pad itself -- the fab guarantees the pad gaps."""
    if ok is None: ok=mask_for(ln,net,w,clr,ignore)
    for p,q in zip(pts,pts[1:]):
        n=max(2,int(math.hypot(q[0]-p[0],q[1]-p[1])/G)+2)
        for i in range(n+1):
            t=i/n; x=p[0]+(q[0]-p[0])*t; y=p[1]+(q[1]-p[1])*t
            gx,gy=int(round(x/G)),int(round(y/G))
            if not (0<=gx<NX and 0<=gy<NY): return False
            if ok[gx,gy]: continue
            if exempt and in_rects(x,y,exempt): continue
            return False
    return True

def blocker(pts,ln,net,w,clr,ignore=None,exempt=None):
    arr=occ[LI[ln]]; rad=int(math.ceil((w/2+clr)/G)); v=nidx[net]
    bad=(arr!=0)&(arr!=v)
    if ignore: bad &= (arr!=nidx[ignore])
    ok=~ndimage.binary_dilation(bad,structure=np.ones((2*rad+1,2*rad+1),bool))
    inv={i:n for n,i in nidx.items()}
    for p,q in zip(pts,pts[1:]):
        n=max(2,int(math.hypot(q[0]-p[0],q[1]-p[1])/G)+2)
        for i in range(n+1):
            t=i/n; x=p[0]+(q[0]-p[0])*t; y=p[1]+(q[1]-p[1])*t
            gx,gy=int(round(x/G)),int(round(y/G))
            if not ok[gx,gy]:
                if exempt and in_rects(x,y,exempt): continue
                sub=arr[max(0,gx-rad):gx+rad+1,max(0,gy-rad):gy+rad+1]
                who=sorted({inv.get(int(z),f'#{z}') for z in np.unique(sub) if z!=0 and z!=v})
                return f'at ({x:.2f},{y:.2f}) blocked by {who[:3]}'
    return 'clear'

def snap(v): return round(v/G)*G
def lshape(a,b,first):
    (x0,y0),(x1,y1)=a,b; dx,dy=x1-x0,y1-y0
    if abs(dx)<1e-9 or abs(dy)<1e-9: return [a,b]
    if not DIAG[0]:
        return [a,((x1,y0) if first=='h' else (x0,y1)),b]      # true right angle
    sx,sy=(1 if dx>0 else -1),(1 if dy>0 else -1); m=min(abs(dx),abs(dy))
    p1,p2 = ((x1-sx*m,y0),(x1,y0+sy*m)) if first=='h' else ((x0,y1-sy*m),(x0+sx*m,y1))
    pts=[a,p1,p2,b]
    return [p for i,p in enumerate(pts) if i==0 or abs(p[0]-pts[i-1][0])>1e-9 or abs(p[1]-pts[i-1][1])>1e-9]
def trim45(pts):
    if not DIAG[0]:
        d=[pts[0]]
        for q in pts[1:]:
            if abs(q[0]-d[-1][0])>1e-9 or abs(q[1]-d[-1][1])>1e-9: d.append(q)
        return d
    out=[pts[0]]
    for i in range(1,len(pts)-1):
        p,c,n=pts[i-1],pts[i],pts[i+1]
        d1=(c[0]-p[0],c[1]-p[1]); d2=(n[0]-c[0],n[1]-c[1])
        l1=math.hypot(*d1); l2=math.hypot(*d2)
        if l1<1e-9 or l2<1e-9: continue
        k=min(l1,l2)/2
        out.append((c[0]-d1[0]/l1*k, c[1]-d1[1]/l1*k)); out.append((c[0]+d2[0]/l2*k, c[1]+d2[1]/l2*k))
    out.append(pts[-1]); d=[out[0]]
    for p in out[1:]:
        if abs(p[0]-d[-1][0])>1e-9 or abs(p[1]-d[-1][1])>1e-9: d.append(p)
    return d
def zshape(a,b,axis,frac):
    (x0,y0),(x1,y1)=a,b
    if axis=='h':
        xm=snap(x0+(x1-x0)*frac); return trim45([a,(xm,y0),(xm,y1),b])
    ym=snap(y0+(y1-y0)*frac); return trim45([a,(x0,ym),(x1,ym),b])
def plen(p): return sum(math.hypot(b[0]-a[0],b[1]-a[1]) for a,b in zip(p,p[1:]))

def escape(pad,L=None,toward=None):
    """A pad's escape direction is its own long axis, pointing away from the body.

    v2 took one row axis per footprint, which is nonsense for a 112-pad module with
    pads on all four edges: it sent the SD bus sideways out of a 1.0 mm-pitch row
    straight into its neighbours, so every one of those nets failed at the first cell.
    """
    w,h = pad['w'],pad['h']
    if abs(pad['rot'])%180==90: w,h = h,w
    dx,dy = pad['x']-pad['fx'], pad['y']-pad['fy']
    if w > h*1.2:   dirs=[((1,0),w/2),((-1,0),w/2)]          # long in x -> escape in x
    elif h > w*1.2: dirs=[((0,1),h/2),((0,-1),h/2)]
    else:           dirs=[((1,0),w/2),((-1,0),w/2),((0,1),h/2),((0,-1),h/2)]
    _L = ESC if L is None else L
    # outward first: a castellated pad routed inward disappears under the module
    def outward(d): return d[0]*dx + d[1]*dy
    dirs.sort(key=lambda z: -outward(z[0]))
    out=[]
    for d,off in dirs:
        out.append((snap(pad['x']+d[0]*(off+_L)),pad['y']) if d[0] else (pad['x'],snap(pad['y']+d[1]*(off+_L))))
    if toward is not None:
        # keep outward-first ordering but let a clearly better-aimed exit win
        out.sort(key=lambda e: math.hypot(e[0]-toward[0],e[1]-toward[1]))
    return (pad['x'],pad['y']), out

D8=[(1,0),(-1,0),(0,1),(0,-1),(1,1),(1,-1),(-1,1),(-1,-1)]
D4=D8[:4]
# Style weights.  TURN keeps the picture orthogonal, OFFAX makes F.Cu trend
# horizontal and B.Cu vertical, VIAC stops the router stitching for fun.
# HW is a weighted-A* factor: the step costs above are ~1..10 while a plain
# Euclidean heuristic is ~1 per cell, so unweighted search wanders the whole
# board before committing.  HW restores useful guidance.
TURN,OFFAX,VIAC,HW = 6.0,1.2,15.0,3.0
def maze2(a,b,net,w,clr,layers,cap=1200000,endlayers=None,pad_mm=12.0,hw=None):
    hw=HW if hw is None else hw
    m=int(pad_mm/G)
    box=(max(0,int(min(a[0],b[0])/G)-m), max(0,int(min(a[1],b[1])/G)-m),
         min(NX,int(max(a[0],b[0])/G)+m), min(NY,int(max(a[1],b[1])/G)+m))
    oks={ln:mask_for(ln,net,w,clr,box=box) for ln in layers}
    el=set(range(len(layers))) if endlayers is None else {i for i,ln in enumerate(layers) if ln in endlayers}
    sx,sy=int(round(a[0]/G)),int(round(a[1]/G)); tx,ty=int(round(b[0]/G)),int(round(b[1]/G))
    start=(0,sx,sy,8); g={start:0.}; prev={}; pq=[(0.,start)]; seen=None; n=0
    rv=int(math.ceil((VIA_D/2+clr)/G))
    while pq:
        n+=1
        if n>cap: break
        f,cur=heapq.heappop(pq); cl,cx,cy,cd=cur
        if (cx,cy)==(tx,ty) and cl in el: seen=cur; break
        base=g[cur]; ln=layers[cl]; pref=PREF[ln]; ok=oks[ln]
        NB = D8 if DIAG[0] else D4
        for di,(dx,dy) in enumerate(NB):
            nx,ny=cx+dx,cy+dy
            if not (0<=nx<NX and 0<=ny<NY): continue
            if (nx,ny)!=(tx,ty) and not ok[nx,ny]: continue
            c=1.0 if dx==0 or dy==0 else 1.414
            if cd!=8 and di!=cd: c+=TURN
            ax='h' if dy==0 else ('v' if dx==0 else 'd')
            c += OFFAX*0.5 if ax=='d' else (OFFAX if ax!=pref else 0)
            ns=(cl,nx,ny,di); ng=base+c
            if ng<g.get(ns,1e18):
                g[ns]=ng; prev[ns]=cur; heapq.heappush(pq,(ng+hw*math.hypot(nx-tx,ny-ty),ns))
        if len(layers)>1:
            nl=1-cl
            if rv<=cx<NX-rv and rv<=cy<NY-rv and oks[layers[nl]][cx,cy] and can_via(cx*G,cy*G,net,clr):
                ns=(nl,cx,cy,8); ng=base+VIAC
                if ng<g.get(ns,1e18):
                    g[ns]=ng; prev[ns]=cur; heapq.heappush(pq,(ng+hw*math.hypot(cx-tx,cy-ty),ns))
    if seen is None: return None
    ch=[seen]
    while ch[-1] in prev: ch.append(prev[ch[-1]])
    ch.reverse()
    runs=[]; vias=[]; cl=ch[0][0]; pts=[(ch[0][1]*G,ch[0][2]*G)]
    for p,q in zip(ch,ch[1:]):
        if q[0]!=p[0]:
            runs.append((layers[cl],pts)); vias.append((p[1]*G,p[2]*G)); cl=q[0]; pts=[(q[1]*G,q[2]*G)]
        else: pts.append((q[1]*G,q[2]*G))
    runs.append((layers[cl],pts))
    out=[]
    for ln,ps in runs:
        if len(ps)<2: continue
        o=[ps[0]]
        for i in range(1,len(ps)-1):
            d1=(ps[i][0]-ps[i-1][0],ps[i][1]-ps[i-1][1]); d2=(ps[i+1][0]-ps[i][0],ps[i+1][1]-ps[i][1])
            if abs(d1[0]-d2[0])>1e-9 or abs(d1[1]-d2[1])>1e-9: o.append(ps[i])
        o.append(ps[-1]); out.append((ln,o))
    return (out,vias) if out else None

def cls_of(n):
    if n.startswith('CSI_'): return 'MIPI'
    # The J1<->U2 stubs are ~5 mm of the USB channel through the ESD part.  Holding
    # them to 0.27/0.18 makes them unroutable through U2's pad field, and a 0.2 mm
    # trace over 5 mm is ~95 ohm instead of 90 -- electrically irrelevant at USB 2.0.
    # The impedance-controlled run is U2<->U1, which keeps the USB class.
    if n.endswith('_CON'): return 'DEF'
    if n.startswith('USB_D'): return 'USB'
    if n in ('+5V','+3V3','+1V8','GND','VBUS_IN'): return 'PWR'
    return 'DEF'

def esc_geom(q,wid,clr):
    """Escape width/clearance scaled to the pad.  A 0.3 mm stub at 0.2 mm clearance
    needs 0.35 mm of lateral room; an FPC pin at 0.5 mm pitch offers exactly 0.35 mm,
    so it fails by one cell.  A 0.3 mm-wide pin cannot carry more than a 0.2 mm trace
    anyway, so the stub follows the pad and fattens once clear."""
    short=min(q['w'],q['h'])
    return (min(wid,max(0.2,short*0.8)), min(clr,CLR['DEF']) if short<0.45 else clr)
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

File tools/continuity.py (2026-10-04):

"""LocalCam-1 continuity + clearance test — independent of KiCad's own DRC.

  python3 continuity.py            # test LocalCam1.kicad_pcb in this folder
  python3 continuity.py board.kicad_pcb

Rasterises all copper (pads, tracks, vias, filled zones) per layer at 0.02 mm,
joins layers through vias and through-hole pads, then for each net counts how many
electrically separate islands its copper forms.

  1 island  = net is fully continuous          OK
  N islands = net is in N disconnected pieces  -> N-1 connections still missing

Also reports any two different nets closer than the clearance (a short waiting to happen).

NOTE: zones only count if KiCad has filled them — press B in the PCB editor and save
first, otherwise pours are ignored and ground will look disconnected.
"""
import sys, os, math
import numpy as np
from scipy import ndimage
sys.path.insert(0, '/home/claude')
HERE = os.path.dirname(os.path.abspath(__file__)); sys.path.insert(0, HERE)
from sexp import parse, find, val, unq

G      = 0.05 if '--fine' not in sys.argv else 0.02   # mm per cell
CLEAR  = 0.15                                   # mm, min clearance to flag
LAY    = ['F.Cu', 'In1.Cu', 'In2.Cu', 'B.Cu']
LI     = {n: i for i, n in enumerate(LAY)}
ARGS   = [a for a in sys.argv[1:] if not a.startswith('--')]
PATH   = ARGS[0] if ARGS else os.path.join(HERE, 'LocalCam1.kicad_pcb')
DOCLR  = '--clearance' in sys.argv

b = parse(open(PATH).read())
W = H = 0
for l in find(b, 'gr_line'):
    for k in ('start', 'end'):
        a = find(l, k)[0]; W = max(W, float(a[1])); H = max(H, float(a[2]))
for l in find(b, 'gr_arc'):
    for k in ('start', 'mid', 'end'):
        for a in find(l, k): W = max(W, float(a[1])); H = max(H, float(a[2]))
NX, NY = int(W / G) + 2, int(H / G) + 2

own  = [np.zeros((NX, NY), np.int32) for _ in LAY]     # net id per cell per layer
vmap = [np.zeros((NX, NY), bool) for _ in LAY]         # cell is joined to the layer below/above

def xf(X, Y, r, x, y):
    t = math.radians(r)
    return (X + x*math.cos(t) + y*math.sin(t), Y - x*math.sin(t) + y*math.cos(t))

def rect(arr, cx, cy, w, h, rot, v):
    if abs(rot) % 180 == 90: w, h = h, w
    arr[max(0, int((cx-w/2)/G)):int((cx+w/2)/G)+1,
        max(0, int((cy-h/2)/G)):int((cy+h/2)/G)+1] = v

def disc(arr, cx, cy, d, v):
    r = d/2; x0, x1 = max(0,int((cx-r)/G)), min(NX-1,int((cx+r)/G))
    y0, y1 = max(0,int((cy-r)/G)), min(NY-1,int((cy+r)/G))
    ys, xs = np.ogrid[y0:y1+1, x0:x1+1]
    m = ((xs*G-cx)**2 + (ys*G-cy)**2) <= r*r
    sub = arr[x0:x1+1, y0:y1+1]
    sub[m.T] = v

# ---- collect nets -------------------------------------------------------
import re as _re
_all = sorted(set(_re.findall(r'\(net "([^"]*)"\)', open(PATH).read())))
_idx = {nm: i+1 for i, nm in enumerate(_all)}
netname = {i+1: nm for i, nm in enumerate(_all)}
def nid(node):
    x = find(node, 'net')
    if not x: return 0
    t = x[0][1]
    return _idx.get(unq(t), 0) if t.startswith('"') else int(t)

# ---- pads ---------------------------------------------------------------
npad = 0; padlist = []
for fp in find(b, 'footprint'):
    at = find(fp, 'at')[0]; X, Y = float(at[1]), float(at[2])
    r = float(at[3]) if len(at) > 3 else 0.0
    ref = [unq(p[2]) for p in find(fp, 'property') if unq(p[1]) == 'Reference'][0]
    for p in find(fp, 'pad'):
        a = find(p, 'at')[0]; s = find(p, 'size')[0]
        pr = float(a[3]) if len(a) > 3 else 0.0
        px, py = xf(X, Y, r, float(a[1]), float(a[2]))
        v = nid(p)
        if v == 0: continue
        thru = p[2] in ('thru_hole', 'np_thru_hole')
        lays = [unq(z) for z in find(p, 'layers')[0][1:]]
        tgt = LAY if thru else [z for z in LAY if z in lays or '*.Cu' in lays]
        for ln in tgt:
            rect(own[LI[ln]], px, py, float(s[1]), float(s[2]), pr, v)
            if thru: vmap[LI[ln]][max(0,int((px-0.1)/G)):int((px+0.1)/G)+1,
                                  max(0,int((py-0.1)/G)):int((py+0.1)/G)+1] = True
        padlist.append((ref, unq(p[1]), v)); npad += 1

# ---- tracks -------------------------------------------------------------
nseg = 0
for s in find(b, 'segment'):
    ln = unq(val(s, 'layer'))
    if ln not in LI: continue
    a = find(s, 'start')[0]; c = find(s, 'end')[0]; w = float(val(s, 'width')); v = nid(s)
    x0, y0, x1, y1 = float(a[1]), float(a[2]), float(c[1]), float(c[2])
    n = int(max(abs(x1-x0), abs(y1-y0))/G) + 2
    for i in range(n+1):
        t = i/n; disc(own[LI[ln]], x0+(x1-x0)*t, y0+(y1-y0)*t, w, v)
    nseg += 1

# ---- vias ---------------------------------------------------------------
nvia = 0
for vn in find(b, 'via'):
    a = find(vn, 'at')[0]; d = float(val(vn, 'size')); v = nid(vn)
    x, y = float(a[1]), float(a[2])
    lays = [unq(z) for z in find(vn, 'layers')[0][1:]] if find(vn, 'layers') else LAY
    span = LAY if len(lays) < 2 else LAY[LI[lays[0]]:LI[lays[-1]]+1] if lays[0] in LI and lays[-1] in LI else LAY
    for ln in span:
        disc(own[LI[ln]], x, y, d, v)
        vmap[LI[ln]][max(0,int((x-d/4)/G)):int((x+d/4)/G)+1,
                     max(0,int((y-d/4)/G)):int((y+d/4)/G)+1] = True
    nvia += 1

# ---- filled zones -------------------------------------------------------
nzone = 0; unfilled = []
from matplotlib.path import Path as MPath
for z in find(b, 'zone'):
    v = nid(z); zl = unq(val(z, 'layer') or '')
    fills = find(z, 'filled_polygon')
    if not fills:
        unfilled.append((netname.get(v, '?'), zl or 'multi')); continue
    for f in fills:
        ln = unq(val(f, 'layer') or zl)
        if ln not in LI: continue
        pts = [(float(a[1]), float(a[2])) for a in find(find(f, 'pts')[0], 'xy')]
        if len(pts) < 3: continue
        xs = [p[0] for p in pts]; ys = [p[1] for p in pts]
        x0, x1 = max(0,int(min(xs)/G)), min(NX-1,int(max(xs)/G))
        y0, y1 = max(0,int(min(ys)/G)), min(NY-1,int(max(ys)/G))
        if x1 <= x0 or y1 <= y0: continue
        gx, gy = np.meshgrid(np.arange(x0,x1+1)*G, np.arange(y0,y1+1)*G, indexing='ij')
        inside = MPath(pts).contains_points(np.column_stack([gx.ravel(), gy.ravel()]))
        sub = own[LI[ln]][x0:x1+1, y0:y1+1]
        sub[inside.reshape(sub.shape) & (sub == 0)] = v
        nzone += 1

# ---- continuity: label islands per net, joined across layers by vias ----
print(f'board {W:.0f} x {H:.0f} mm   pads {npad}  tracks {nseg}  vias {nvia}  filled zone polys {nzone}')
if unfilled:
    print(f'!! {len(unfilled)} zone(s) NOT FILLED - press B in KiCad and save, or pours are ignored:')
    for n, l in unfilled[:8]: print(f'     {n} on {l}')
print()
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

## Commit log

2026-10-04 LocalCam-1 Rev A2: local-only WiFi camera on Luckfox Core1106
    A 75x44mm 4-layer board that turns a Core1106 module (RV1106G3) into a network
    camera that never leaves the LAN. MIPI CSI-2 sensor in over an FPC, H.264/H.265
    encoded on-chip, RTSP to a local Frigate NVR, object detection on the module's
    own 1 TOPS NPU.
    State: 226 of 228 netted pads connected. Two signals still need a trace --
    SD_D3 at J2.2 and VBUS_DET at R7.2 -- and both want a part nudged rather than
    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
    [LocalCam1.kicad_pcb, LocalCam1.kicad_sch]
2026-10-10 Fix DRC errors; set via rules to JLC 4-layer limits
    - Via rules: min diameter 0.45, min hole 0.2, min annular 0.075 mm
    (JLC's no-extra-cost tier). Clears 135 errors on the 0.45/0.25 GND
    stitching vias.
    - Remove a stray no-net via off the board edge and a zero-length
    NPOR_RST track.
    - Move TP2 0.4 mm right to clear the C8 courtyard.
    - Fix starved thermals: GND tie tracks on C8.2 and U1.55, solid zone
    connection on R8.2.
    - Refill zones.
    - Includes in-progress schematic and board edits.
    [LocalCam1.kicad_pcb, LocalCam1.kicad_sch]
2026-10-10 AAAAA it should cook a bit more now
    [LocalCam1.kicad_pcb]
